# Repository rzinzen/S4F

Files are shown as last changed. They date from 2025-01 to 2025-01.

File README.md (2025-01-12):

# S4F
This project titled S4F ("Showers for Future") was designed and realized by Oliver R. Zinzen as a Science Fair project.
It descroibes an adapter compatible with 1/2-inch water pipes that houses a thermistor as a temperature sensor and which is to be combined with a commercially available Hall-Effect based 5V flow sensor. These sensors are meant to be connected to an Arduino Uno via a custom-solderd shield that also accomodates at 16x2 LCD display.
The following files are provided:
- Arduino Sketches
  - a main operating program called "S4F_vX.X" to read the sensors, address the LCD and monitor an input button.
  - a utility program called "S4F_CPLutility_v1.0" that helps determine the CPL (Counts per Liter) value 
- A wiring diagram for the electronics and how they are connected to the Arduino Uno
- A soldering plan for the custom shield
- STL 3D-model files so that the following items can be printed:
  - the Thermistor Housing with intrerenal 1/2-inch pipe threads
  - the enclosure that contains the electronics (Arduino Uno, electronics sield, main switch, battery, input button)

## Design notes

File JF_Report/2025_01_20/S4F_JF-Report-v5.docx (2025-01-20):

# S 4 F

# (Showers4Future)

Ein Jugend Forscht Projekt von

Oliver R. Zinzen (15 Jahre)

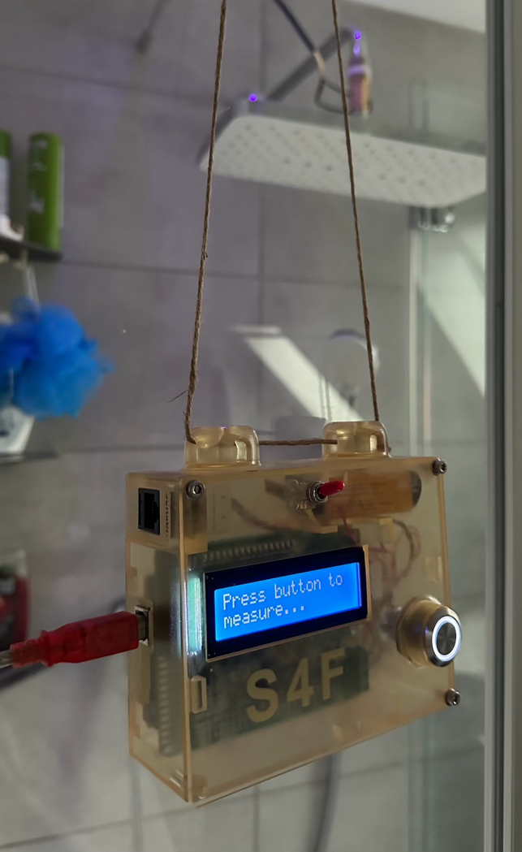
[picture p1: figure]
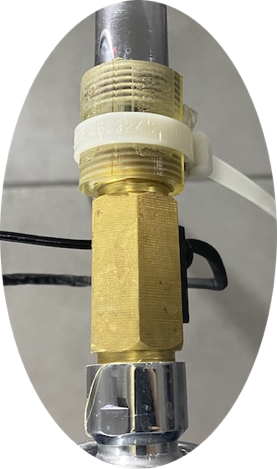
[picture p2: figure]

Fachgebiet: Physik

Wettbewerbsjahr: 2024/25

Bundesland: Brandenburg (West)

Barnim Gymnasium Bernau

Klasse 9M

Erarbeitungsort: hauptsächlich Zuhause

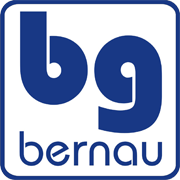
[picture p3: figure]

Betreuung:

- Fr. Hänsel (Mathematik & Physik)
- Fr. Gust (Mathematik & Physik)

# Projektüberblick

In meinem Projekt geht es darum, Wasser und Energie bewusster und sparsamer zu nutzen.

Ich habe einen Adapter für die Dusche entwickelt, mit dem die verbrauchte Wassermenge und -temperatur gemessen werden können. Ziel ist es, Verbrauchsinformationen leicht zugänglich zu machen, da ich überzeugt bin, dass solche Daten unser Verhalten positiv beeinflussen können, um Ressourcen und Kosten zu sparen.

Auf die Idee kam ich aus zwei Gründen: Zum einen bereiten uns die steigenden Energiepreise Sorgen, und zum anderen bedroht der Klimawandel unsere Zukunft. Ich glaube, dass intelligente technologische Ansätze uns dabei unterstützen können, umweltbewusster zu handeln.

Der von mir entwickelte Adapter wird beispielsweise an einer Duscharmatur installiert. Mithilfe eines Arduino-Mikrocontrollers werden die Sensoren für Temperatur und Wassergeschwindigkeit ausgelesen und die Daten dem Nutzer auf einem LCD-Display angezeigt. Ich habe den Adapter erfolgreich gebaut und bei uns zu Hause getestet, um erste Erfahrungen zu sammeln. Ich nenne ihn S4F („Showers for Future“).

Der Adapter hat gut funktioniert, aber es gibt noch viele Möglichkeiten zur Verbesserung. Zum Beispiel könnte er kleiner und kompakter gebaut werden, und es wäre sinnvoll, die erfassten Daten kabellos zu übertragen. Gerne würde ich S4F auch bei anderen Familien testen, um herauszufinden, ob die bereitgestellten Informationen nicht nur bei uns, sondern auch bei anderen Nutzern ein bewussteres und sparsameres Verhalten im Umgang mit Wasser und Energie fördern.

(Für Bild: siehe Titelseite)

# Inhaltsverzeichnis

# 1 Fachliche Kurzfassung

In meinem Projekt „S4F“ habe ich ein Gerät entwickelt, das Nutzer über ihren Wasser- und Energieverbrauch informiert.

Ein 3D-gedruckter Adapter, der zwischen Wasserarmatur (z.B. Duscharmatur) und Schlauch geschraubt wird, enthält Fluss- und Temperatursensoren und ist mit einem Arduino-Mikrocontroller verbunden. Die von mir entwickelte Software misst die Wassergeschwindigkeit und Temperatur und zeigt die ermittelten Werte auf einem LCD-Display an. Nach der Dusche berechnet das Gerät Verbrauchsdaten wie Duschzeit, Wassermenge, Durchschnittstemperatur, Energieverbrauch und Kosten und informiert den Nutzer darüber.

Das Ziel des Projekts ist es, den Nutzern Daten zur Verfügung zu stellen, die ein bewussteres und umweltfreundlicheres Verhalten ermöglichen.

# 2 Motivation und Fragestellung

Wasser und Energie sind essentielle Ressourcen, die wir täglich nutzen – sei es beim Duschen, Baden oder Händewaschen. Doch meist wissen wir nicht, wie viel Wasser und Energie wir dabei tatsächlich verbrauchen. In meiner Facharbeit möchte ich ein Gerät entwickeln, das hilft, unseren Wasser- und Energieverbrauch besser zu verstehen und diese wertvollen Ressourcen einzusparen. Hierzu plane ich, einen Adapter zu entwickeln, der an eine Wasserarmatur angeschlossen werden kann. Dieser Adapter misst Wasserfluss und Temperatur und informiert den Nutzer über den Verbrauch.

Die zentrale Fragestellung meiner Arbeit lautet: "Wie entwickle ich eine Elektronik, die Wasserfluss und Temperatur misst, die gesammelten Daten an den Nutzer übermittelt und wie integriere ich die Sensoren in einen Armatur-Adapter?" Mein Adapter soll "Showers4Future" (kurz: "S4F") heißen.

Dieses Thema fasziniert mich, weil es Technik und Umweltschutz miteinander verbindet. Ich bin überzeugt, dass wir genaue Informationen über unseren Verbrauch benötigen, um unser Verhalten gezielt und nachhaltig zu ändern. S4F soll uns dabei unterstützen, achtsamer mit Wasser und Energie umzugehen.

# 3 Hintergrund und theoretische Grundlagen

Die Idee für S4F kam mir im Winter 2022. Meine Familie war besorgt über die steigenden Energiekosten nach Russlands Invasion der Ukraine. Ich lebe mit meinen Eltern und drei Brüdern zusammen und mir wurde klar, dass wir viel Energie für Duschen verwenden. Aber niemand konnte mir genau sagen, wie viel Wasser und Energie wir tatsächlich beim Duschen verbrauchen. Also habe ich beschlossen, diesen Verbrauch zu messen.

Ich bin überzeugt, dass wir, wenn wir genaue Informationen über unseren Wasser- und Energieverbrauch hätten, gezielt darauf reagieren könnten. S4F soll nicht nur helfen wichtige Ressourcen zum Wohl der Umwelt zu schonen, sondern auch unsere Ausgaben zu reduzieren.

## 3.1 Temperaturmessung

Um die Temperatur zu messen, dachte ich sofort an einen Thermistor. Dieses elektronische Bauteil war mir zuvor in einem Arduino-Starter-Kit[^1] begegnet. Ein Thermistor ist ein elektrischer Widerstand mit der besonderen Eigenschaft, dass sein Widerstandswert von der Temperatur abhängt.

Bei meinen Recherchen im Internet stieß ich auf die sogenannte Steinhart-Hart-Gleichung. Mit dieser Gleichung lässt sich die Temperatur anhand des Widerstandswerts eines Thermistors berechnen[^2]. Die Herausforderung bestand jedoch darin, den Widerstand des Thermistors auszulesen, da dies nicht direkt mit einem Mikrocontroller wie z.B. einem Arduino möglich ist.

Dank meines Elektronik-Lernsets wusste ich, dass der Widerstand eines Thermistors indirekt gemessen werden kann, indem man ihn in einem Spannungsteiler verwendet und die Spannung über den Thermistor misst. Wenn die Spannung über den Thermistor und die Gesamtspannung des Spannungsteilers bekannt sind, lässt sich mithilfe des Ohm’schen Gesetzes der Widerstand des Thermistors berechnen. Den so ermittelten Widerstandswert kann ich schließlich in die Steinhart-Hart-Gleichung einsetzen, um die Temperatur zu bestimmen.

## 3.2 Wasserverbrauch

Ich habe mich im Internet nach Sensoren umgesehen, mit denen ich den Wasserverbrauch messen kann und bin dabei auf sogenannte Durchflusssensoren (Flow Sensors) gestoßen, die meist auf dem Hall-Effekt basieren.

Der Hall-Effekt beschreibt, dass Elektronen in einer geraden Linie durch eine leitfähige Platte wandern, wenn ein elektrischer Strom durch die Platte fließt. Befindet sich jedoch ein Magnet in der Nähe, werden die Elektronen zur Seite abgelenkt, wodurch eine Spannung über der Platte entsteht. Diese Spannung kann gemessen werden[^3].

Ein Durchflusssensor (Hall-Effekt-Sensor, HES) nutzt diesen Effekt: Er besitzt einen Propeller, der sich durch den Wasserfluss dreht. Die Propellerflügel sind dabei mit kleinen Magneten ausgestattet. Wenn sich der Propeller dreht, passieren die Magneten wiederholt den Hall-Effekt-Sensor und erzeugen Spannungsimpulse. Ich gehe davon aus, dass die Frequenz dieser Impulse proportional zur Wassergeschwindigkeit ist.

Diese Spannungsimpulse und ihre Frequenz sollte ich mit einem Mikrocontroller erfassen und zählen können, um so den Wasserverbrauch zu bestimmen.

## 3.3 Microcontroller

Um den Thermistor und den Hall-Effekt-Sensor (HES) auszulesen, plane ich, einen Mikrocontroller zu verwenden. Es gibt derzeit mehrere beliebte Plattformen, wie den Raspberry Pi und Arduino. Mikrocontroller sind Chips, die programmierbar sind und Signale verarbeiten und ausgeben können. Solche Mikrocontroller sind als sogenannte Entwicklungsboards (Dev.Kits) erhältlich, bei denen der Mikrocontroller-Chip über General Purpose Input/Output (GPIO)-Pins zugänglich ist. An diese Pins können Sensoren, Motoren oder andere Geräte angeschlossen werden, die durch Programmierung ausgelesen oder gesteuert werden können.

In einem vorherigen Projekt habe ich zusammen mit meinem Bruder einen Raspberry Pi verwendet, um in Python eine selbstoptimierende Wind- und Solaranlage (SoWiSo) zu entwickeln. Dabei fiel mir jedoch auf, dass der Raspberry Pi ein vollwertiger Unix-Computer ist und vergleichsweise viel Energie verbraucht. Da das S4F-Gerät batteriebetrieben sein soll, ist Energieeffizienz sehr wichtig.

Aus diesem Grund habe ich mich für die Arduino-Plattform entschieden. Arduino-Boards sind deutlich energiesparsamer als der Raspberry Pi und bieten dennoch ausreichend Leistung für mein Vorhaben. Das Arduino Uno R3 Dev. Kit kann entweder über eine 5 V-USB-Verbindung oder eine andere Gleichstromquelle (bis zu 12 V) betrieben werden. Es verfügt über 14 digitale und 6 analoge GPIO-Pins, die sich flexibel als Eingänge zum Einlesen von Signalen oder als Ausgänge zum Steuern von Geräten programmieren lassen.

Die Arduino-Plattform verwendet C++ als Programmiersprache. Der Code kann mit der kostenlosen Entwicklungsumgebung Arduino IDE (Integrated Development Environment)[^4] geschrieben und getestet werden. Zudem bietet die Arduino-Community eine ausgezeichnete Unterstützung: Es gibt zahlreiche Anleitungen, Foren und Codebeispiele, die den Einstieg erleichtern[^5]. Darüber hinaus ist es relativ einfach, ein Arduino-Board mit einem LCD-Display zu verbinden, um dem Nutzer Anweisungen anzuzeigen oder Daten zu präsentieren.

# 4 Vorgehensweise, Materialien und Methoden

## 4.1 Elektronik und Prototyp

Den ersten Prototyp zur Auslesung der Sensoren mit einem Arduino habe ich mithilfe einer Steckplatine entwickelt. Diese ermöglicht es, elektronische Komponenten durch einfaches Einstecken von Jumper-Kabeln zu verbinden. Eine Liste der verwendeten Komponenten befindet sich im Anhang (9.1). Die wichtigsten Komponenten sind:

- Arduino Uno R3 Dev. Kit: Ein Arduino-Entwicklerboard als Steuereinheit.
- Durchflusssensor[^6]: Kann mithilfe des Hall-Effekts Durchflussmengen zwischen 1 und 30 L/min messen.
- Thermistor: Ein NTC-Temperatursensor (TRU Components, Modell MJSTS-103-3950-1-600-3D[^7]) mit einem 10 kΩ Referenzwiderstand bei 25 °C.
- Steckplatine und Elektronikkomponenten: Die Steckplatine sowie verschiedene Bauteile (Widerstände, Taster, Potentiometer, Jumper-Kabel, LCD-Display) stammen aus mehreren Elektronik-Lernsets1,[^8],[^9].

Mit dieser Hardware konnte ich die grundlegenden Funktionen des Prototyps testen und die Sensoren erfolgreich mit dem Arduino integrieren.

## 4.2 Programmieren

Für die Programmierung habe ich die Software Arduino IDE4 verwendet. Mit dieser Entwicklungsumgebung kann man C++ Code schreiben, auf Syntaxfehler prüfen und anschließend auf ein Arduino-Board übertragen. Ein besonders nützliches Feature der Arduino IDE ist der Serial Monitor. Dieser ermöglicht es, dass der Arduino während des Programmablaufs Nachrichten sendet. So können potenzielle Probleme im Code einfach diagnostiziert und behoben werden. Die Grundlagen der Programmierung eines Arduino habe ich mithilfe eines Arduino-Übungsbuchs8 gelernt. Bei Fragen oder Herausforderungen konnte ich meist hilfreiche Antworten im Arduino-Wiki5 finden.

## 4.3 Löten

Nachdem ich einen funktionierenden Prototyp auf einer Steckplatine gebaut hatte, plante ich, ein „Shield“ zu erstellen. Ein Shield ist eine Platine, die auf den Arduino aufgesteckt werden kann und auf der alle Schaltkreise fest verlötet sind.

Zunächst habe ich mit der CAD-Software Autodesk Eagle[^10] die Schaltkreise aufgezeichnet und dokumentiert, wie diese mit dem Arduino und dem LCD-Display verdrahtet waren. Anschließend entwickelte ich einen detaillierten Lötplan.

Die Umsetzung erfolgte auf einer Lochrasterplatine (90 mm x 70 mm, Rastermaß 2,54 mm). Alle benötigten Komponenten wurden gemäß des Lötplans auf die Platine aufgebracht, mit Silberdraht verbunden und verlötet, um eine robuste und dauerhafte Verbindung zu gewährleisten.

## 4.4 3D-Design & 3D-Druck

Für das S4F-Gerät habe ich zwei Bauteile selbst gedruckt: die Thermistor-Halterung, die mit der Armatur und dem Flusssensor verschraubt wird, sowie das Gehäuse für die Elektronik. Beide Teile habe ich mit der Software Autodesk Fusion 360[^11] entworfen.

Die 3D-Modelle habe ich anschließend als STL-Dateien exportiert und mit einem 3D-Drucker (Keyence Agilsta 3200 W[^12]) gedruckt. Der Agilsta ist ein professioneller 3D-Drucker, der anstelle des herkömmlichen PLA-Filaments einen foto-aktivierbaren Druck-Harz verwendet. Dadurch kann der Agilsta eine höhere Auflösung sowie bessere Materialfestigkeit und Hitzebeständigkeit erreichen.

## 4.5 Implementierung zu Hause

Das erste S4F Gerät habe ich in unserer Dusche zu Hause installiert, und wir haben es circa eine Woche lang benutzt. Von unseren ersten Erfahrungen werde ich berichten.

# 5 Ergebnisse

Die Entwicklung des S4F-Geräts hat längere Zeit in Anspruch genommen. Besonders beim ersten Prototyp auf der Steckplatine musste ich regelmäßig Komponenten ändern und umstecken, was parallel zur Softwareentwicklung lief. Zum Beispiel, als ich auf die Idee kam, ein LCD-Display zu verwenden, musste ich die Verkabelung komplett überarbeiten, um die benötigten GPIO-Pins zu belegen und die Betriebssoftware darauf abzustimmen. Ebenso, als ich mehr über die Thermistor-Temperatur-Berechnung recherchierte, musste ich einen neuen Spannungsteiler implementieren. In den folgenden Ergebnissen werde ich deshalb hauptsächlich die Endergebnisse darstellen, aber keine detaillierte Beschreibung der Umwege und Anpassungen während der Entwicklung geben.

## 5.1 Der Prototyp

Den ersten Prototypen habe ich auf einer Steckplatine verkabelt, wobei der Arduino über USB mit 5 V versorgt wurde. Das Steckbrett ist in Abbildung 1B dargestellt, und der schematische Schaltplan ist in Abbildung 1 A zu sehen. Die wichtigsten Komponenten des Prototyps sind:

- Arduino Uno R3 Mikrocontroller mit 14 digitalen GPIOs und 6 analogen GPIOs (die auch als digitale Pins genutzt werden können). Zusätzlich verfügt der Arduino über mehrere Power-Pins, von denen ich den „5 V“-Pin als positiven Pol (5 V+) und den „Gnd“-Pin als negativen Pol (Gnd) für meine Schaltung verwendet habe.
  - 16x2 LCD-Display Modul: Das Display kann 16 Zeichen in 2 Reihen darstellen. Wie im Arduino Wiki beschrieben[^13], ist das LCD-Display mit 5 V+ und Gnd verbunden. Der V0-Pin des Displays ist mit einem 10 kΩ Potentiometer verbunden, um den Displaykontrast durch Regulierung des elektrischen Potentials am V0-Pin einzustellen. Um dem Arduino das Senden von Text an das Display zu ermöglichen, ist der Arduino mit den Pins En, RS sowie D4, D5, D6 und D7 des Displays verbunden. Dadurch werden insgesamt 6 digitale GPIO-Pins des Arduinos benötigt.
  - Taster: Ein Taster ermöglicht es dem Arduino, auf Nutzereingaben zu reagieren. Wenn der Taster betätigt wird, schließt er einen Stromkreis zwischen 5 V+ und Gnd über einen 10 kΩ Widerstand, wodurch der digitale Pin auf 5 V gesetzt wird. Ein 7. Digitaler Pin wird so programmiert, dass er den Unterschied zwischen 0V (LOW, offen) und 5 V (HIGH, geschlossen) erkennt, womit der Arduino auf die Knopfbetätigung reagieren kann.
  - Hall-Effekt-Sensor: Der Hall-Effekt-Sensor hat drei Kabel. Zwei (rot und schwarz) dienen der Stromversorgung und sind an 5 V+ und Gnd angeschlossen. Über das dritte Kabel (grün) wird der Hall-Impuls an einen 8. digitalen GPIO-Pin übertragen, die vom Arduino dann gezählt werden können.
  - Thermistor: Um den Thermistor auszulesen, verwende ich einen Spannungsteiler, bei dem ein konstant bleibender Widerstand (R5) und der temperaturabhängige Thermistor in Reihe zwischen 5 V+ und Gnd geschaltet sind. Da der Thermistor einen Referenzwert von 10 kΩ bei 25°C hat, habe ich einen 10 kΩ Widerstand als konstante Komponente verwendet. So wird die Spannung bei 25 °C halbiert und Widerstandsunterschiede im Thermistor sollten gut erfassbar sein. Die Spannung über den Thermistor wird an einen 9. GPIO-Pin des Arduinos übertragen. Dies muss ein analoger Pin sein, damit der Arduino die Größe der Spannung wie in 5.2 beschrieben auslesen kann.

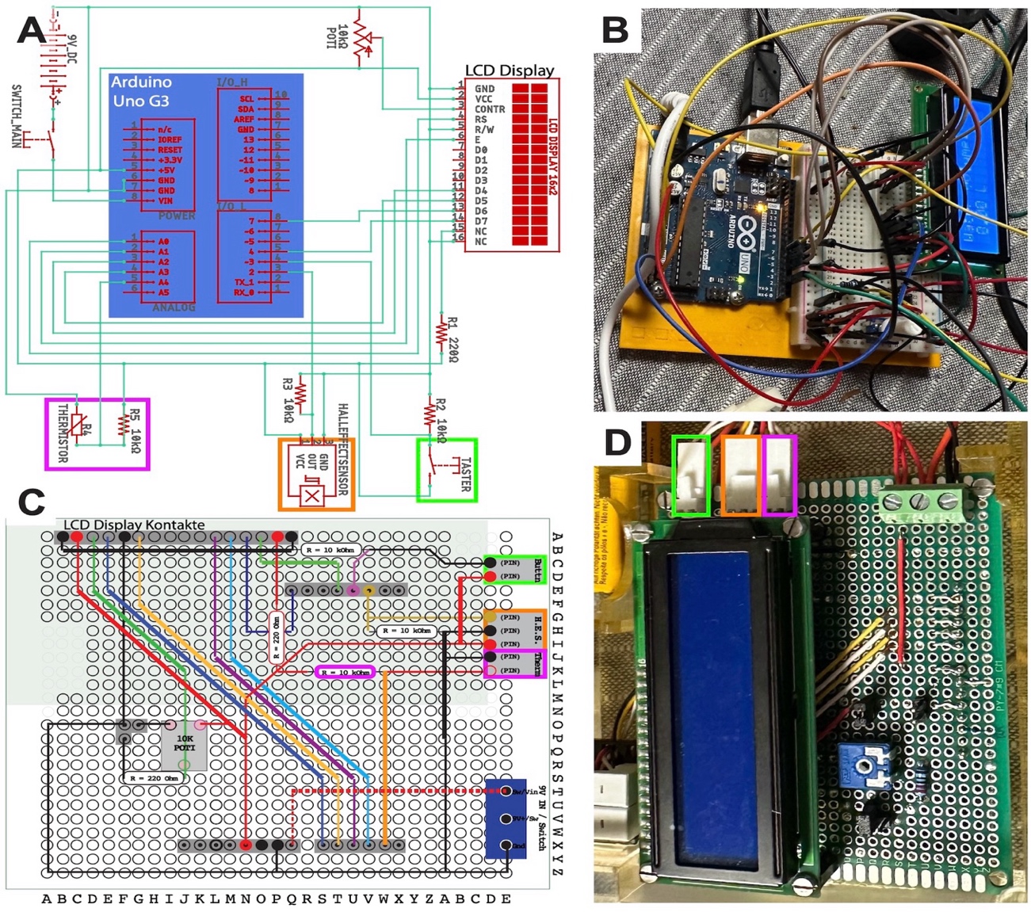
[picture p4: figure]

Abbildung 1: Prototyp-Schaltplan uns Shield-Entwicklung

Der Schaltplan (A) basiert auf dem Steckbrett Prototyp (B). Auf (A) basierend wurde ein Lötplan (C) entwickelt was mir erlaubte ein Arduino-Shield mit fest verlöteten Elektronik-komponenten zu bauen (D). Einige Komponenten sind umrahmt (Thermistor in rosa, HES in orange, Input Taster in hellgrün). Detaillierte Pläne stehen zum Download auf GitHub bereit[^14].
(Alle Abbildungen in dieser Arbeit wurden eigenständig erstellt.)

Nachdem der funktionierende Schaltplan stand (Abbildung 1A, B), um den Taster, den Thermistor und den Hall-Effekt-Sensor auszulesen, habe ich mir einen Lötplan erstellt (Abbildung 1C). Anschließend habe ich die Schaltung auf einer Lochrasterplatine umgesetzt (Abbildung 1D). Da ich eine Platine mit einem Lochrastermaß von 2,54 mm verwendete, konnte ich die Lötstiftleisten so anordnen, dass die Platine direkt auf den Arduino aufgesteckt werden konnte, um eine stabile Verbindung zu gewährleisten. Zusätzlich habe ich eine Kontaktleiste eingelötet, sodass das LCD-Display mit seinen 16 Stiften direkt auf die Platine aufgesetzt werden kann. Dies ermöglichte es, das Display und den Arduino bei Bedarf wieder zu trennen, falls ich Änderungen an der Platine vornehmen muss.

## 5.2 Implementierung des Thermistors zur Temperaturmessung

### 5.2.1 Berechnung des Thermistorwiderstands

Da der Thermistrorwiderstand R_(Ther) mit einem Arduino nicht direkt ausgelesen werden kann, werde ich ihn mit Hilfe des Ohm’schen Gesetzes[^15] anhand der gemessenen Spannung berechnen ( R_(Ther) = (U_(Ther))/I ). Die Spannung über den Thermistor U_(Ther) kann über die analogen GPIO-Pins eingelesen werden, da diese mit einem 10-Bit-ADC (Analog-to-Digital Converter) ausgestattet sind. Der ADC wandelt die Spannung am Pin relativ zur internen Referenzspannung ( U_(In) = 5 V ) in einen Wert zwischen 0 – 1023 (10-Bit-Auflösung) um.

Ich benutze einen Spannungsteiler, der aus zwei Widerständen in Reihe besteht: R1 (ein konstanter Widerstand von 10 kΩ) und RTher (der Widerstand des Thermistors).

Der Gesamtwiderstand des Spannungsteilers ist: R_(Ges) =R_1 +R_(Ther)

Nach dem Ohm‘schen Gesetz15 gilt: U_(In) =R_(Ges) ∙I_(Ges) =(R_1 +R_(Ther) )∙I

Daraus folgt: I_(Ges) = (U_(In))/((R_1 +R_(Ther) ))

Die 5 V Eingangsspannung teilt sich über Widerstände in Reihe auf: U_(In) =U_1 +U_(Ther)

Die Spannung über den Thermistor ist nach dem Ohm‘schen Gesetz definiert als:

U_(Ther) =R_(Ther) ∙I_(Ther) ⇔ I_(Ther) = (U_(Ther))/(R_(Ther))

Da die Stromstärke überall im Stromkreis gleich ist gilt I_(Ges) =I_(Ther) und der Widerstand des Thermistors RTher kann berechnet werden:

(U_(Ther))/(R_(Ther)) =(U_(In))/((R_1 +R_(Ther) ))

Nach Umstellung: R_(Ther) =(R_1)/(((U_(In))/(U_(Ther)) - 1))

Mit R_1 =10 kΩ , U_(In) =5 V , und dem Wert für UTher, den der Arduino über den ADC ausliest kann der Thermistorwiderstand R_(Ther) berechnet werden.

### 5.2.2 Temperaturberechnung

Mit Hilfe der Steinhart-Hart-Gleichung lässt sich die Temperatur T aus dem Widerstand R_(Ther) berechnen:

T_(Kelvin) =1/((A + B∙ ln(R_(Ther) )+ C∙ (ln(R_(Ther) ))^3 ))

Die Werte A, B, und C Thermistor-spezifische Konstanten, die ich mit einem Online-Thermistor Rechner[^16] und den Widerstandswerten aus dem Thermistor Datenblatt7 ermittelt habe:

A=1,105646556∙10^(-3) B=2,369707092∙10^(-4) C=8,420273017∙10^(-8)

Um die Temperatur in °C umzurechnen, ziehe ich anschließend noch 273,15 ab: T_(Celsius) = T_(Kelvin) – 273,15

## 5.3 Ermittlung des CPL-Werts

Um eine zuverlässige Konstante zur Umrechnung der Hall-Effekt-Impulse in Liter zu ermitteln, habe ich die CPL-Konstante (Counts per Liter) bestimmt. Diese Konstante ermöglicht es dem Arduino, das verbrauchte Wasservolumen durch einfache Division der gezählten Impulse durch den CPL-Wert zu berechnen.

### 5.3.1 Versuchsaufbau

Ich habe ein Utility-Programm (Arduino Sketch verfügbar auf GitHub14) geschrieben, dass die Hall-Effekt-Impulse zählen. Der Start und Stopp der Zählung erfolgten über einen Knopf. Der Versuch wurde folgendermaßen durchgeführt:

1. Durchflusssensor wurde direkt an der Duscharmatur installiert.
2. Ein Eimer wurde mit Markierungen bei 5 L, 8 L und 10 L versehen.
3. Während das Wasser in den Eimer lief, zählte das Programm die Impulse. Nach Erreichen einer bestimmten Markierung wurde die Zählung gestoppt.

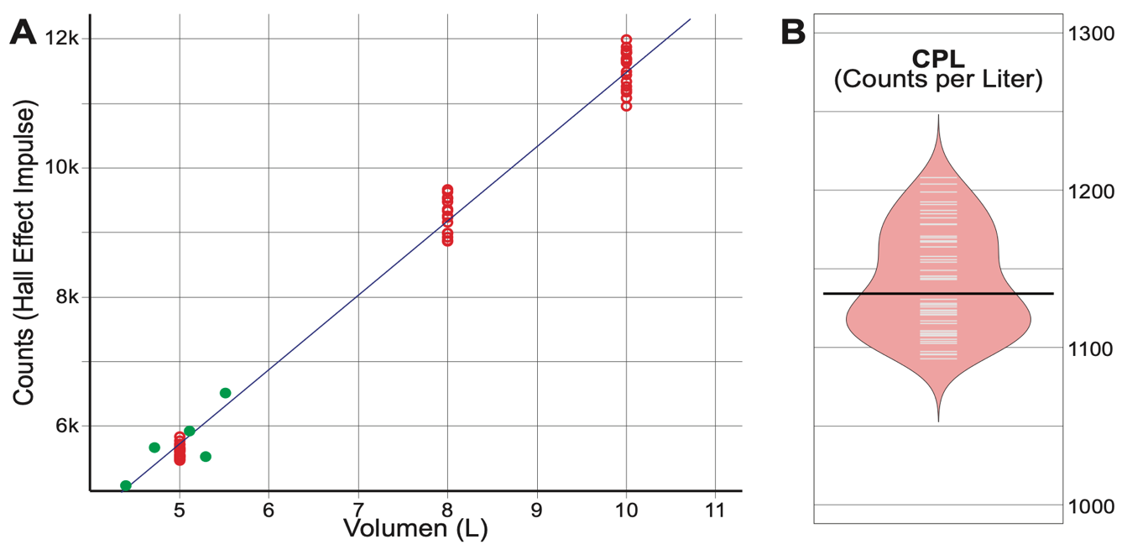
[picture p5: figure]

Abbildung 2: CPL-Ermittlung.

(A) Die roten Punkte sind die gemessenen Impulszahlen des HES. Die Trendlinie durch den Null-Punkt hat einen R²-Wert von 0,9991. Die grünen Punkte sind Punktprüfungen zur Validierung des CPL-Werts.
(B) Die 51 Messwerte sind in einem Bean-Plot als Counts pro Liter dargestellt und zeigen eine enge Verteilung, Median = 1134,2 CPL.

4. Variationen: Der Test wurde mit verschiedenen Wassermengen und Wassergeschwindigkeiten (Hahnöffnung) durchgeführt.

Ich habe diesen Vorgang 51-mal wiederholt und dabei die gezählten Impulse sowie die jeweilige Wassermenge notiert. Alle Messwerte sind im Anhang 9.1 aufgeführt.

### 5.3.2 Datenanalyse

Ein Scatterplot der Count-Werte für 5 L, 8 L und 10 L (Abbildung 2A) zeigt eine nahezu lineare Beziehung zwischen den gezählten Impulsen und der Wassermenge. Eine Trendlinie, berechnet in Excel, liefert einen R²-Wert von 0,9991. Dies deutet darauf hin, dass die CPL-Konstante eine präzise Vorhersage der verbrauchten Wassermenge ermöglicht. Die Trendlinie wird durch die lineare Gleichung y=1148,3∙x beschrieben, wobei die Steigung der CPL-Wert ist:

CPL_(lin) =1148,3

Eine Bean-Plot-Darstellung (Abbildung 2B) der auf 1 L-normalisierten Counts (CPL) verdeutlicht die enge Verteilung der Messwerte im Bereich von ca. 1100 bis 1200 CPL, mit einem Median=1134,2 CPL . Dies ist ein CPL-Wert, der auf einer statistischen Verteilung der Datenpunkte beruht.

CPL_(stat) =1134,2

Auch den Durchschnitt der 51 CPL-Werte könnte man nehmen um den Arduino Impulszählungen in Wasservolumen umrechnen zu lassen:

CPL_(Schnitt) =1141,25

### 5.3.3 Validierung des CPL-Werts

Zur Validierung des CPL-Werts habe ich Test durchgeführt. Ich habe den Eimer mehrmals für eine unbestimmte Zeit (10 – 30 Sekunden) gefüllt während der Arduino die Impulse zählte. Die exakte Wassermenge habe ich anschließend mit einer Küchenwaage bestimmt (1 g Wasser = 1 mL). Die Ergebnisse sind als grüne Punkte im Scatterplot (Abbildung 2A) eingezeichnet und Tabelle 1 aufgeführt

Das gemessene Volumen habe ich mit den für alle 3 CPL-Werte ermittelt, wobei ich die Genauigkeit der 3 CPL-Werte vergleichen wollte. Die Ergebnisse sind in Tabelle 1 aufgeführt.

Tabelle 1: Validierung des bestimmten CPL-Werts

| | | CPLLin = 1148,3 | | CPLStat = 1134,2 | | CPLSchnitt = 1141,25
Nr. | Counts | f | Erwartet (L) | Fehler (%) | Erwartet (L) | Fehler (%) | Erwartet (L) | Fehler (%)
1 | 5098 | 4,385 | 4,440 | 1,245 | 4,495 | 2,504 | 4,467 | 1,871
2 | 5935 | 5,107 | 5,169 | 1,204 | 5,233 | 2,463 | 5,200 | 1,830
3 | 5549 | 5,289 | 4,832 | -8,634 | 4,892 | -7,498 | 4,862 | -8,069
4 | 5680 | 4,708 | 4,946 | 5,065 | 5,008 | 6,371 | 4,977 | 5,714
5 | 6522 | 5,509 | 5,680 | 3,099 | 5,750 | 4,380 | 5,715 | 3,735
Fehler-Durchschnitt: | | | | 1,40 | | 1,64 | | 1,02

Obwohl alle 3 CPL-Werte gute vorhersagen trafen, war der Durchschnittswert etwas besser, denn die berechneten Werte wichen im Schnitt um weniger als ±2 % von der gemessenen Wassermenge ab. Dies zeigt die die Genauigkeit der CPL-Konstante und ich werde den Wert CPL = 1141,25 in meinem Arduino Sketch verwenden.

## 5.4 Die Software

Ein Arduino-Programm wird als “Sketch” bezeichnet. Der S4F-Sketch für Version 2.1[^17] umfasst 354 Zeilen und ist auf GitHub verfügbar14. Der Code ist ausführlich kommentiert, um die einzelnen Schritte und die Funktionsweise des Programms zu verdeutlichen. Die Programmstruktur ist in Abbildung 3 dargestellt. Das Programm ist in verschiedene sogenannte Funktionen unterteilt, wobei jede Funktion einen bestimmten logischen Ablauf umfasst. Diese Funktionen können miteinander kombiniert werden, um die gewünschte Programmlogik zu realisieren.

Wenn das S4F-Gerät gestartet wird, bootet der Arduino direkt in das Betriebsprogramm. Zunächst wird eine library eingebunden, die die Kommunikation mit dem LCD-Display ermöglicht. Anschließend werden innerhalb von Millisekunden verschiedene Variablen und Konstanten definiert, darunter die GPIO-Pins für den Taster, das LCD-Display und den Hall-Effekt-Sensor. Auch thermistorspezifischen Konstanten (A, B, C) sowie CPL werden an dieser Stelle definiert. Ein Arduino-Sketch besteht immer aus zwei Hauptfunktionen: setup() und loop().

In der setup()-Funktion wird festgelegt, wie sich die einzelnen Pins verhalten sollen. Beispielsweise wird der Pin für den Taster („ButtonPin“) sowie der für den Hall-Effekt-Sensor („HallPin“) als „INPUT“ definiert, sodass der Arduino diese Pins kontinuierlich überwachen kann. Der HallPin wird zusätzlich mit einem attachInterrupt()[^18] versehen, wodurch der Arduino unabhängig vom restlichen Programm Spannungsänderungen an diesem Pin registriert. Jede Spannungsänderung – also jeder Impuls des Hall-Effekt-Sensors – ruft die Funktion CountHallPulses() auf, die eine Variable namens HallCount um 1 erhöht und damit die Impulse zählt.

Zusätzlich werden in der setup()-Funktion alle relevanten Variablen auf ihren Anfangswert gesetzt. Danach wird eine Willkommensnachricht auf dem LCD-Display angezeigt, die den Benutzer auffordert, den Taster zu drücken, um die Messungen zu starten. Das Programm wartet anschließend in einer Schleife (while-Loop), bis der Taster gedrückt wird und sich damit die Spannung am ButtonPin sich ändert.

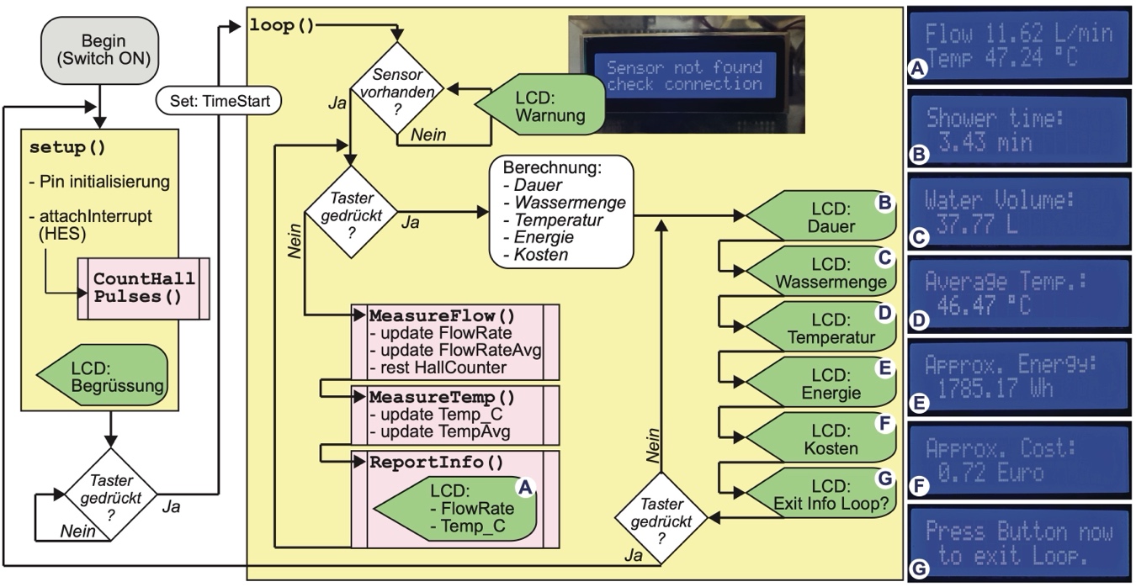
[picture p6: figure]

Abbildung 3: Diagramm der Software-Logik (Version 2.1) mit LCD-Display Beispielen

Nach Betätigung des Tasters wird die Startzeit (TimeStart) festgelegt, und das Programm wechselt zur Hauptfunktion eines jeden Arduino-Sketches: der loop()-Funktion. Diese wird kontinuierlich wiederholt und bildet das Herzstück des Programms.

Zu Beginn der loop()-Funktion überprüft das Programm, ob die Sensoren angeschlossen sind. Falls der Thermistor-Schaltkreis offen ist (keine Sensoren angeschlossen), ist der Widerstand unendlich groß, was zu einem Temperaturwert von -273,15 °C (0 K) führt. In diesem Fall zeigt das Display eine Fehlermeldung an und fordert den Benutzer auf, die Sensorverbindungen zu prüfen.

Wenn die Sensoren korrekt arbeiten, beginnt das Programm mit den Messungen. Alle sechs Sekunden wird die Funktion MeasureFlow() aufgerufen, um die aktuelle Durchflussrate zu berechnen. Die Wassertemperatur wird alle zwei Sekunden mit der Funktion MeasureTemp() gemessen. Beide Werte werden im Zwei-Sekunden-Takt mit ReportInfo() auf dem Display aktualisiert.

Die Funktion MeasureFlow() berechnet die aktuelle Durchflussrate (FlowRate) in L/Minute, indem sie die Anzahl der gezählten Hall-Impulse (HallCount) durch die Konstante CPL teilt und das Ergebnis mit 10 multipliziert (da die Funktion alle 6 Sekunden aufgerufen wird). Zusätzlich wird der Durchschnitt der Durchflussrate berechnet. Abschließend setzt die Funktion HallCount auf 0 zurück, um die nächste Messung vorzubereiten. Die Funktion MeasureTemp() berechnet die aktuelle Wassertemperatur (Temp_C), wie in Abschnitt 5.2 beschrieben. Auch hier wird der Durchschnittswert der Temperatur berechnet.

Wenn der Taster nach der Dusche erneut gedrückt wird, beendet das Programm den Messzyklus und definiert die Stopp-Zeit. Anschließend werden die ermittelten Werte nacheinander auf dem Display angezeigt:

- Duschzeit: Duration(min)= TimeStart-TimeStop
- Wasserverbrauch: Volume(L) = FlowRateAvg(L/min) ∙ Duration(min)
- Schnitttemperatur: TempAvg(°C)
- Energieverbrauch: Energy(Wh) = (Volume(L)∙c_Water(kWh)∙(TempAvg(°C)-TempBase(°C)))/(1000 (L∙°C) ∙ 0,7)
- Kosten: Cost(Euro) = (Energy∙EnergyPrice)+(Volume∙WaterPrice)

Die letzten beiden Werte – Energieverbrauch und Kosten – dienen lediglich der Orientierung, da sie von mehreren Faktoren beeinflusst werden und daher weniger präzise sind. Der Energieverbrauch hängt insbesondere von der spezifischen Wärmekapazität des Wassers (c_Water), der Temperatur des kalten Leitungswassers (TempBase) sowie von der Effizienz des Warmwasserbereitungs- und Speichersystems ab. Da die Effizienz solcher Systeme typischerweise zwischen 60 % und 80 % liegt, habe ich einen realistischen Wert von 70 % verwendet und den Energiewert entsprechend nach oben angepasst, indem ich durch 0,7 teile.

Die Berechnung der Kosten ist ebenfalls ungenau, da sie von den lokalen Energie- und Wasserpreisen abhängt. Der Energiepreis wird variieren, je nachdem, ob das Wasser z.B. mit Strom, Gas oder Öl erhitzt wird. Für die Berechnung habe ich Werte basierend auf realistischen Preisen im Landkreis Barnim verwendet[^19]: 0,28 Euro/kWh Energie und 5,86 Euro/m³ Wasser (inkl. Abwasser).

## 5.5 3D-Design und Druck

Um den Temperatursensor zu integrieren, habe ich ein Gehäuse für den Thermistor entworfen und mit einem 3D-Drucker hergestellt (Abbildung 4A). Da Wasserarmaturen in der Regel ein ½-Zoll-Gewinde besitzen und der Durchflusssensor auf beiden Seiten mit einem ½-Zoll-Außengewinde ausgestattet ist, entschied ich mich, das Thermistorgehäuse mit ½-Zoll-Innengewinden zu entwerfen. Wenn der Fluss- und der Temperatursensor miteinander verschraubt werden, ergibt sich an einem Ende ein Innen- und am anderen Ende ein Außengewinde. Dadurch kann der Adapter problemlos zwischen Armatur und Schlauch montiert werden. Der Thermistor wird mittig in das Gehäuse eingesetzt und mit Silikon wasserdicht versiegelt. Im Inneren des Gehäuses befinden sich zwei Ablagen, die Platz für Gummidichtungen bieten (Abbildung 4B).

Das Gehäuse für die Elektronik wurde exakt auf die Maße des Arduinos, der Platine und des LCD-Displays abgestimmt (Abbildung 4C, D). Der Arduino wird eingelegt, so dass der USB-B-Anschluss zugänglich bleibt. Anschließend wird das verlötete Elektronik-Shield auf den Arduino gesteckt und mit dem Gehäuse verschraubt. Danach wird das LCD-Display auf das Shield aufgesteckt und mit Schrauben befestigt. Eine 9 V-Batterie wird in die vorgesehene Aussparung eingelegt und mit dem Shield verbunden. Die Sensoren werden über einen RJ45-Keystone-Stecker[^20] angeschlossen, der in das Gehäuse integriert wird und mit den entsprechenden Ports des Shields verbunden ist. Im Gehäusedeckel befinden sich ein Schalter, mit dem die Batterie vom Stromkreis getrennt werden kann, sowie ein Taster, der mit dem Knopf-Port des Shields verbunden ist. Schließlich wird der Deckel auf das Gehäuse geschraubt, sodass das LCD-Display durch eine Aussparung sichtbar ist. Das Gerät ist damit einsatzbereit. Am Gehäuse befindet sich eine Halterung, die es ermöglicht, das S4F-System außen an der Dusche zu befestigen. So können die Daten während des Duschens abgelesen werden (siehe Bild auf Titelseite).

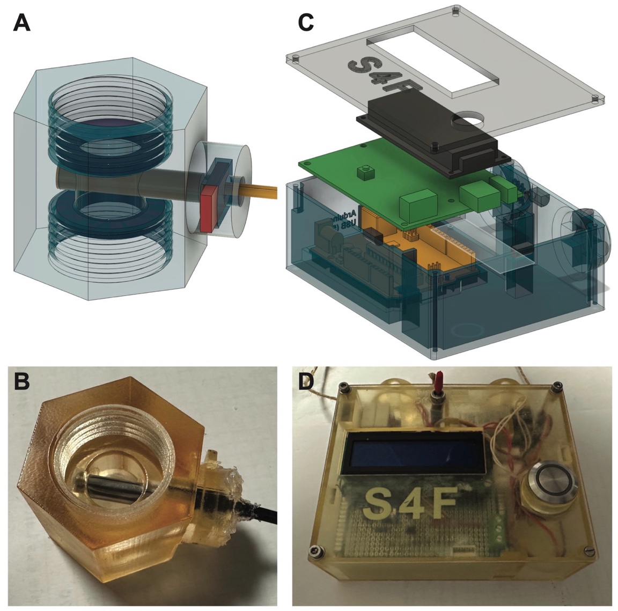
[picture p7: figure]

Abbildung 4: 3D-Modelle und Druckergebnisse

Zu sehen sind die 3D-Modelle für (A) die Thermistorhalterung und (C) das Gehäuse für die Elektronik. (B) und (D) zeigen die gedruckten und zusammengebauten Komponenten.

# 6 Ergebnisdiskussion, Fazit und Ausblick

In meinem Projekt „S4F“ habe ich einen Adapter entwickelt, der auf gängige Wasserarmaturen mit ½-Zoll-Gewinde passt. Dieser Adapter enthält Sensoren, die Wassermenge und -temperatur messen. Die Sensoren sind über eine eigens entwickelte Elektronik mit einem Arduino-Mikrocontroller verbunden. Arduino, Elektronikplatine und ein LCD-Display sind in einem 3D-gedruckten Gehäuse untergebracht.

Das S4F Arduino Betriebssystem misst kontinuierlich Wassermenge und -temperatur und zeigt die Werte auf dem LCD-Display an. Durch erneuten Knopfdruck beendet der Nutzer das Programm. Anschließend berechnet und zeigt der Arduino 5 Werte: (i) Duschzeit, (ii) Wasserverbrauch, (iii) Durchschnittstemperatur, (iv) Energieverbrauch und (v) ungefähre Kosten.

## 6.1 Erste Eindrücke

Nach der Installation des ersten S4F-Geräts in unserer Dusche haben wir interessante Einblicke in unser Duschverhalten gewonnen. Die gesammelten Daten führten zu spannenden Gesprächen in der Familie. Besonders aufschlussreich war es zu sehen, wer am längsten und wer am heißesten duscht. Unsere Durchschnittswerte sind:

- Duschdauer: 6,92 Minuten
- Wasserverbrauch: 60,02 Liter
- Durchschnittstemperatur: 42,96 °C
- Energieverbrauch: 2510,63 Wh
- Ungefähre Kosten: € 1,07

Die teuerste Dusche, die wir bisher gemessen haben, dauerte 13,61 Minuten bei 46,38 °C, verbrauchte 98,90 L und kostete etwa € 1,88. Diese Zahlen waren für uns ein Weckruf. Bei sechs Familienmitgliedern könnten sich unsere jährlichen Duschkosten auf etwa €2343,30 belaufen (€ 1,07 · 365 Tage · 6 Personen).

Die Informationen, die wir jetzt mit Hilfe der S4F haben, machen uns unseren Ressourcenverbrauch erst richtig bewusst und motivieren uns, nachhaltiger zu handeln. Wir haben uns vorgenommen, unsere Duschgewohnheiten zu ändern, um Wasser, Energie und Kosten zu sparen. Das Material für S4F hat uns ca. € 90 gekostet (siehe 9.1), eine Summe, die wir in wenigen Monaten einsparen könnten.

## 6.2 Zukunft

Es gibt viele Möglichkeiten, S4F weiterzuentwickeln und noch nützlicher zu machen. Meine Mutter wünscht sich z.B., dass das Display die Duschzeit anzeigt, so dass man den Verbrauch besser steuern kann. Sollte ich das Projekt für Jugend forscht 2025/26 weiterverfolgen, würde ich zuerst daran arbeiten, die erfassten Daten nach der Dusche per E-Mail an die Nutzer zu senden. Dafür wäre jedoch ein anderer Mikrocontroller nötig, da der von mir verwendete Arduino Uno G3 nicht kabellos kommunizieren kann. Eine mögliche Alternative wäre der Arduino Uno G4 mit WLAN oder ein ESP32-Mikrocontroller, der sowohl WLAN als auch Bluetooth unterstützt.

Zwar weiß ich noch nicht wie kompliziert es ist mit einem Microcontroller E-Mails zu versenden, aber wenn mir das Gelingt könnte ich das System auch noch verbessern indem vor jeder Dusche ein Benutzer ausgewählt wird. So könnten die Daten personenspezifisch gespeichert und versendet werden. Über einen längeren Zeitraum ließen sich dann individuelle Zeitprofile erstellen.

Die Nutzung von WLAN würde jedoch den Energieverbrauch erhöhen. Derzeit verwende ich eine 9 V-Batterie, die über einen Spannungsregler auf 5 V heruntergeregelt wird. Dabei geht jedoch viel Energie als Wärme verloren. Eine effizientere Lösung wäre ein wiederaufladbarer Akku, der über einen Boost-Converter den Arduino mit stabilen 5 V versorgt. Dies wäre nicht nur energieeffizienter, sondern auch umweltfreundlicher.

Ich kann mir vorstellen, dass ein Unternehmen den S4F Prototyp professionell entwickelt und herstellt. Die Elektronik könnte so miniaturisiert werden, dass der Adapter nur ein wenig größer als der Durchflusssensor selbst wäre, denn der Mikrokontroller-Chip ist nur so groß wie ein Fingernagel. Der Thermistor kann auch wesentlich kleiner sein und direkt beim Propeller angebracht sein. Statt LCD Display könnte das Modul direkt mit einer App (z.B. über Bluetooth) Informationen geben und Daten loggen. Eine Knopfbatterie würde wahrscheinlich genug Strom liefern, aber vielleicht wäre es sogar möglich den Propeller als Turbine zu nutzen um Spannung zu generieren und einen kleinen Akku zu laden[^21].

## 6.3 Ein sozialwissenschaftliches Experiment

Eine weitere interessante Anwendung für S4F wäre ein kleines sozialwissenschaftliches Experiment. Ich könnte ein verbessertes Gerät für einige Wochen an verschiedene Familien meiner Klassenkameraden verleihen. Mit deren Einwilligung könnten die gesammelten Daten über WLAN auch an mich gesendet werden. Den Familien würde ich die ausgewerteten Daten selbstverständlich zur Verfügung stellen. Ich würde die anonymisierten Daten für mein nächstes Jugend forscht-Projekt verwenden, um zu untersuchen, ob und wie sich das Duschverhalten durch den Einsatz von S4F verändert. Das Projekt könnte Aufschluss darüber geben, wie technische Lösungen Menschen zu einem nachhaltigeren Verhalten motivieren können.

# 7 Quellen- und Literaturverzeichnis

# 8 Unterstützungsleistungen

Ich möchte mich besonders bei Fr. Hänsel für ihre Betreuung meiner Jugend Forscht Arbeit bedanken.

Ich möchte mich auch bei Frau Gust bedanken, die meine Facharbeit betreut hat und die mir erlaubt hat die Facharbeit mit dem Jugend Forscht Projekt zu kombinieren.

Ich will mich bei meinem Vater für seine Hilfe beim Löten und Programmieren bedanken.

Schließlich möchte ich mich noch beim BIMSB (Berlin Institute for Medical Systems Biology) bedanken, weil ich dort den 3D-Drucker benutzen durfte.

Ich habe KI in Form von ChatGPT benutzt um meinen selbst-geschriebenen Text auf Rechtschreib- und Grammatikfehler zu prüfen. Die KI hat auch einige Unklarheiten gefunden, die ich überarbeiten konnte. Ich habe alles auf Richtigkeit geprüft.

# 9 Anhang

## 9.1 Teileliste

Nr. | Bauteil | Beschreibung | Kosten (€, ca.)
1 | Arduino Uno G3 | Microcontroller | 14,00
2 | LCD 1602 | LCD Display mit 16 Zeichen in 2 Reihen | 6,00
3 | Steckplatine | In einem Elektronik-Lern-Set vorhanden | 4,00
4 | Jumper Kabel | In einem Elektronik-Lern-Set vorhanden | 1,50
5 | Thermistor | TRU Components MJSTS-103-3950-1-600-3D Temperatursensor, bestellt bei Conrad Elektronik | 2,49
6 | FlowSensor | Messing Gehäuse mit Hall Effekt Sensor Bestellt bei Conrad Amazon | 12,93
7 | Widerstände | In einem Elektronik-Lern-Set vorhanden | 2,00
8 | Knöpfe | In einem Elektronik-Lern-Set vorhanden | 2,00
9 | Lötausrüstung | z.B. Lötzinn, Flux, Lötstation, Schrumpfschlauch, Heisluftpistole, Silberdraht, 3. Hand, usw. (Grundausrüstung - hatten wir zu Hause) | 0,00
10 | Potentiometer | 10kΩ lineares Potentiometer | 2,00
11 | Lochrasterplatine | 70mm x 90mm, Rastermaß 2,54mm, Teil eines Sets, bestellt bei Reichelt Elektronik | 2,60
12 | Taster | TRU Components GQ 19H-S bestellt bei Conrad Elektronik | 6,99
13 | Kippschalter | TRU Components TC-MK245 bestellt bei Conrad Elektronik | 1,99
14 | Harz für 3D-Drucker | Wurde mir gestellt, kosten ungefähr 21,50 + 5,20 | 26,70
15 | RJ45 Keystone | Delock 8703, Buchse zum Anschließen der Sensoren, im Gehäuse mit der Platine verdrahtet, bestellt bei Reichelt | 3,95
16 | LAN Internet Kabel | Hatten wir zuhause; eine Seite abgeschnitten und mit den Sensorkabeln verlötet und verschrumpft. | 0,00
17 | Software | Ich habe nur (für Schüler) kostenlose Software benutzt. | 0,00
| | Summe (ca.): | € 89,15

## 9.2 Messwerte zur CPL-Wert Bestimmung

Nr. | Volumen (L) | Wasserhahn | Füllzeit (sec) | HES Counts | CPL
1 | 5 | ganz offen | 25 | 5716 | 1143,20
2 | 5 | ganz offen | 25 | 5726 | 1145,20
3 | 5 | ganz offen | 24 | 5636 | 1127,20
4 | 5 | ganz offen | 24 | 5519 | 1103,80
5 | 5 | ganz offen | 29 | 5605 | 1121,00
6 | 5 | ganz offen | 23 | 5464 | 1092,80
7 | 5 | ganz offen | 24 | 5540 | 1108,00
8 | 5 | ganz offen | 24 | 5513 | 1102,60
9 | 5 | ganz offen | 25 | 5779 | 1155,80
10 | 5 | tlw. offen | 45 | 5673 | 1134,60
11 | 5 | tlw. offen | 36 | 5544 | 1108,80
12 | 5 | tlw. offen | 43 | 5610 | 1122,00
13 | 5 | tlw. offen | 45 | 5653 | 1130,60
14 | 5 | tlw. offen | 47 | 5553 | 1110,60
15 | 5 | tlw. offen | 47 | 5526 | 1105,20
16 | 5 | tlw. offen | 64 | 5487 | 1097,40
17 | 5 | tlw. offen | 42 | 5640 | 1128,00
18 | 5 | tlw. offen | 44 | 5839 | 1167,80
19 | 5 | tlw. offen | 50 | 5635 | 1127,00
20 | 5 | tlw. offen | 56 | 5477 | 1095,40
21 | 8 | ganz offen | 40 | 9366 | 1170,75
22 | 8 | ganz offen | 39 | 9234 | 1154,25
23 | 8 | ganz offen | 40 | 9263 | 1157,88
24 | 8 | ganz offen | 42 | 9540 | 1192,50
25 | 8 | ganz offen | 43 | 9664 | 1208,00
26 | 8 | ganz offen | 55 | 9631 | 1203,88
27 | 8 | ganz offen | 61 | 9527 | 1190,88
28 | 8 | tlw. offen | 79 | 9340 | 1167,50
29 | 8 | tlw. offen | 73 | 9163 | 1145,38
30 | 8 | tlw. offen | 88 | 8882 | 1110,25
31 | 8 | tlw. offen | 89 | 8859 | 1107,38
32 | 8 | tlw. offen | 104 | 8922 | 1115,25
33 | 8 | tlw. offen | 60 | 9480 | 1185,00
34 | 8 | tlw. offen | 102 | 8985 | 1123,13
35 | 8 | tlw. offen | 79 | 8990 | 1123,75
36 | 10 | ganz offen | 52 | 11988 | 1198,80
37 | 10 | ganz offen | 48 | 11169 | 1116,90
38 | 10 | ganz offen | 52 | 11824 | 1182,40
39 | 10 | ganz offen | 51 | 11670 | 1167,00
40 | 10 | ganz offen | 51 | 11781 | 1178,10
41 | 10 | ganz offen | 50 | 11697 | 1169,70
42 | 10 | ganz offen | 47 | 11207 | 1120,70
43 | 10 | ganz offen | 48 | 11871 | 1187,10
44 | 10 | tlw. offen | 94 | 10958 | 1095,80
45 | 10 | tlw. offen | 72 | 11440 | 1144,00
46 | 10 | tlw. offen | 105 | 11091 | 1109,10
47 | 10 | tlw. offen | 84 | 11258 | 1125,80
48 | 10 | tlw. offen | 99 | 11342 | 1134,20
49 | 10 | tlw. offen | 101 | 11490 | 1149,00
50 | 10 | tlw. offen | 98 | 11639 | 1163,90
51 | 10 | tlw. offen | 102 | 11785 | 1178,50

[^1] Elegoo.com (2025): ELEGOO UNO R3 Project The Most Complete Starter Kit Tutorial, [online] https://eu.elegoo.com/blogs/arduino-projects/elegoo-uno-r3-project-the-most-complete-starter-kit-tutorial [abgerufen am 12.01.2025].
[^2] Wikipedia.org (2025): Steinhart-Hart Gleichung, [online] https://de.wikipedia.org/wiki/Steinhart-Hart-Gleichung [abgerufen am 12.01.2025].
[^3] Wikipedia.org (2025): Hall-Effekt, [online] https://de.wikipedia.org/wiki/Hall-Effekt [abgerufen am 12.01.2025].
[^4] Arduino.cc (2025): Software | Arduino, [online] https://www.arduino.cc/en/software [abgerufen am 12.01.2025].
[^5] Arduino.cc (2025): Arduino Reference, [online] https://www.arduino.cc/reference/cs/ [abgerufen am 12.01.2025].
[^6] Amazon.de (2025): 1-30L / min Wasserdurchflussschalter, [online] https://www.amazon.de/gp/product/B07XDZ25SY/ref=ppx_yo_dt_b_search_asin_image?ie=UTF8&psc=1 [abgerufen am 12.01.2025].
[^7] Conrad.de (2025): TRU COMPONENTS MJSTS-103-3950-1-600-3D, [online] https://www.conrad.de/de/p/tru-components-mjsts-103-3950-1-600-3d-temperatursensor-30-bis-105-c-10-k-3950-k-1570951.html [abgerufen am 12.01.2025].
[^8] Arduino.cc (2025): Arduino Starter Kit Multi-language, [online] https://store.arduino.cc/products/arduino-starter-kit-multi-language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 [abgerufen am 12.01.2025].
[^9] Elegoo.com (2025): ELEGOO 37 in 1 Sensor Modules Kit Tutorial, [online] https://www.elegoo.com/blogs/arduino-projects/elegoo-37-in-1-sensor-modules-kit-tutorial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 [abgerufen am 12.01.2025].
[^10] Autodesk.com (2025): Autodesk Eagle, [online] https://www.autodesk.com/products/eagle/ [abgerufen am 12.01.2025].
[^11] Autodesk.com (2025): Autodesk Fusion, [online] https://www.autodesk.com/products/fusion-360 [abgerufen am 12.01.2025].
[^12] Keyence.de (2025): AGILISTA-3200W, [online] https://www.keyence.de/products/3d-printers/3d-printers/agilista-3100/models/agilista-3200w/ [abgerufen am 12.01.2025].
[^13] Arduino.cc (2025): Liquid Crystal Displays (LCD) with Arduino, [online] https://docs.arduino.cc/learn/electronics/lcd-displays/ [abgerufen am 13.01.2025].
[^14] Github (2025): rzinzen / S4F, [online] https://github.com/rzinzen/S4F [abgerufen am 12.01.2025].
[^15] Fluke (2025): What is Ohm’s Law? (Electrical, Fundamentals), [online] https://www.fluke.com/en/learn/blog/electrical/what-is-ohms-law [abgerufen am 13.01.2025].
[^16] SRS (2025): Thermistor Calculator v1.1, [online] https://www.thinksrs.com/downloads/programs/therm%20calc/ntccalibrator/ntccalculator.html [abgerufen am 12.01.2025].
[^17] Kurz vor Abgabe der Arbeit habe ich Verbesserungen am Code vorgenommen. Die derzeitige Version ist 3.1 und auf GitHub verfügbar14. Änderungen sin in den „Version Notes“ des Codes dokumentiert.
[^18] Arduino.cc (2025): attachInterrupt(), [online] https://www.arduino.cc/reference/cs/language/functions/external-interrupts/attachinterrupt/ [abgerufen am 12.01.2025].
[^19] Stadtwerke Bernau (2025): Stadtwerke Neukunden – NK-Portal, [online] https://kundenportal.stadtwerke-bernau.de/Neukunden/Neukunden/Tarifuebersicht [abgerufen am 12.01.2025].
[^20] Wikipedia.org (2025): Keystone Module, [online] https://en.wikipedia.org/wiki/Keystone_module [abgerufen am 14.01.2025].
[^21] Den Durchflusssensor als Turbine zu verwenden wäre eine sehr komplexe Herausforderung, da dies den Einsatz des Propellers zum Antrieb eines Motors erfordert. Wenn der Motor eine Batterie lädt, entsteht ein erhöhter (wahrscheinlich variabler) Widerstand und der CPL-Wert wäre evtl. variabel.

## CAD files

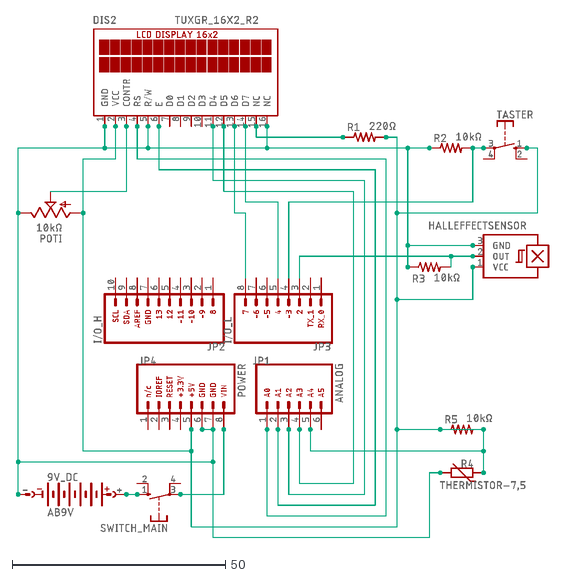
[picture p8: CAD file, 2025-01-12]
WireingDiagram-S4F_Shield.dxf
125.1 x 122.5

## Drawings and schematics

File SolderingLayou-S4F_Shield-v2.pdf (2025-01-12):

# ABCDEFGHIJKLMNOPQRSTUVWXYZABCDE

# Arduino

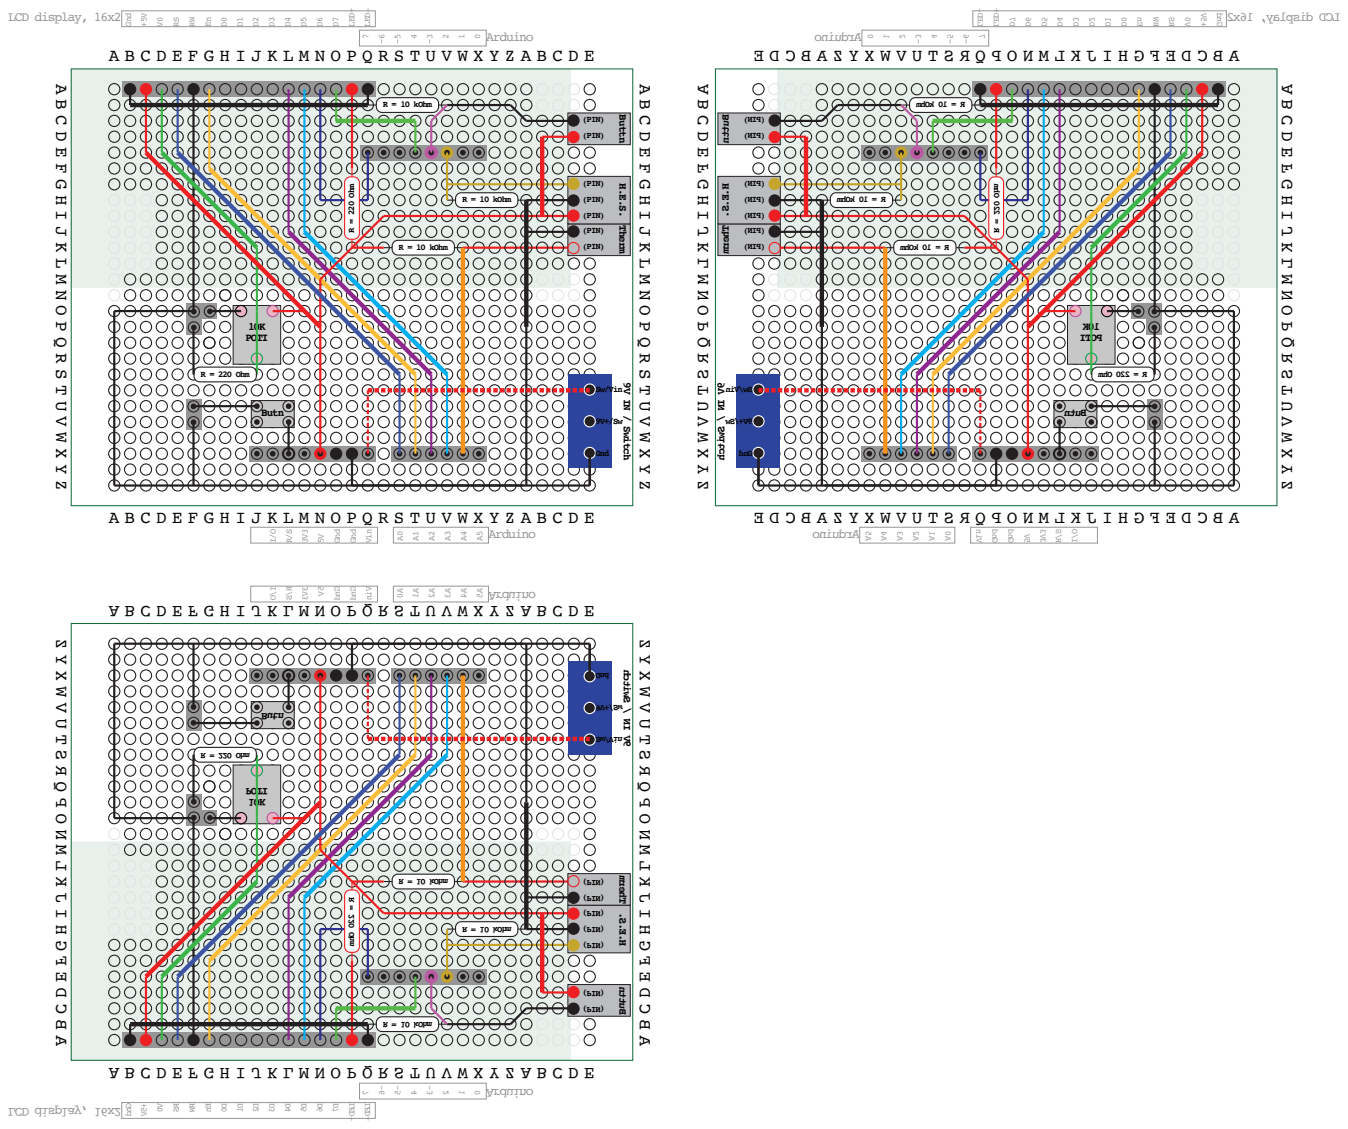
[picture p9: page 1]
LCD display, 16x2; I/O R/S 3V3 5VGnd Gnd Vin; Arduino; ABCDEFGHIJKLMNOPQRSTUVWXYZ; R = 10 kOhm; 10K POTI; Butn; Sw/Vin; Gnd; (PIN) (PIN); (PIN) (PIN) (PIN); R = 220 Ohm; ABCDEFGHIJKLMNOPQRSTUVWXYZABCDE; ABCDEFGHIJKLMNOPQRSTUVWXYZABCDE Gnd +5V V0RSRWEnD0D1D2D3D4D5D6D7LED+ LED- LCD display, 16x2; A0A1A2A3A4A5Arduino 7~6~5 4~3 2 1 0Arduino ABCDEFGHIJKLMNOPQRSTUVWXYZ; POTI; (PIN); Vin; ABCDEFGHIJKLMNOPQRSTUVWXYZ R = 10 kOhm

ABCDEFGHIJKLMNOPQRSTUVWXYZABCDE Gnd +5V V0RSRWEnD0D1D2D3D4D5D6D7LED+ LED-

9V IN / Switch Buttn Therm H.E.S.

9V IN / Switch Buttn Therm H.E.S. R = 10 kOhm

Gnd

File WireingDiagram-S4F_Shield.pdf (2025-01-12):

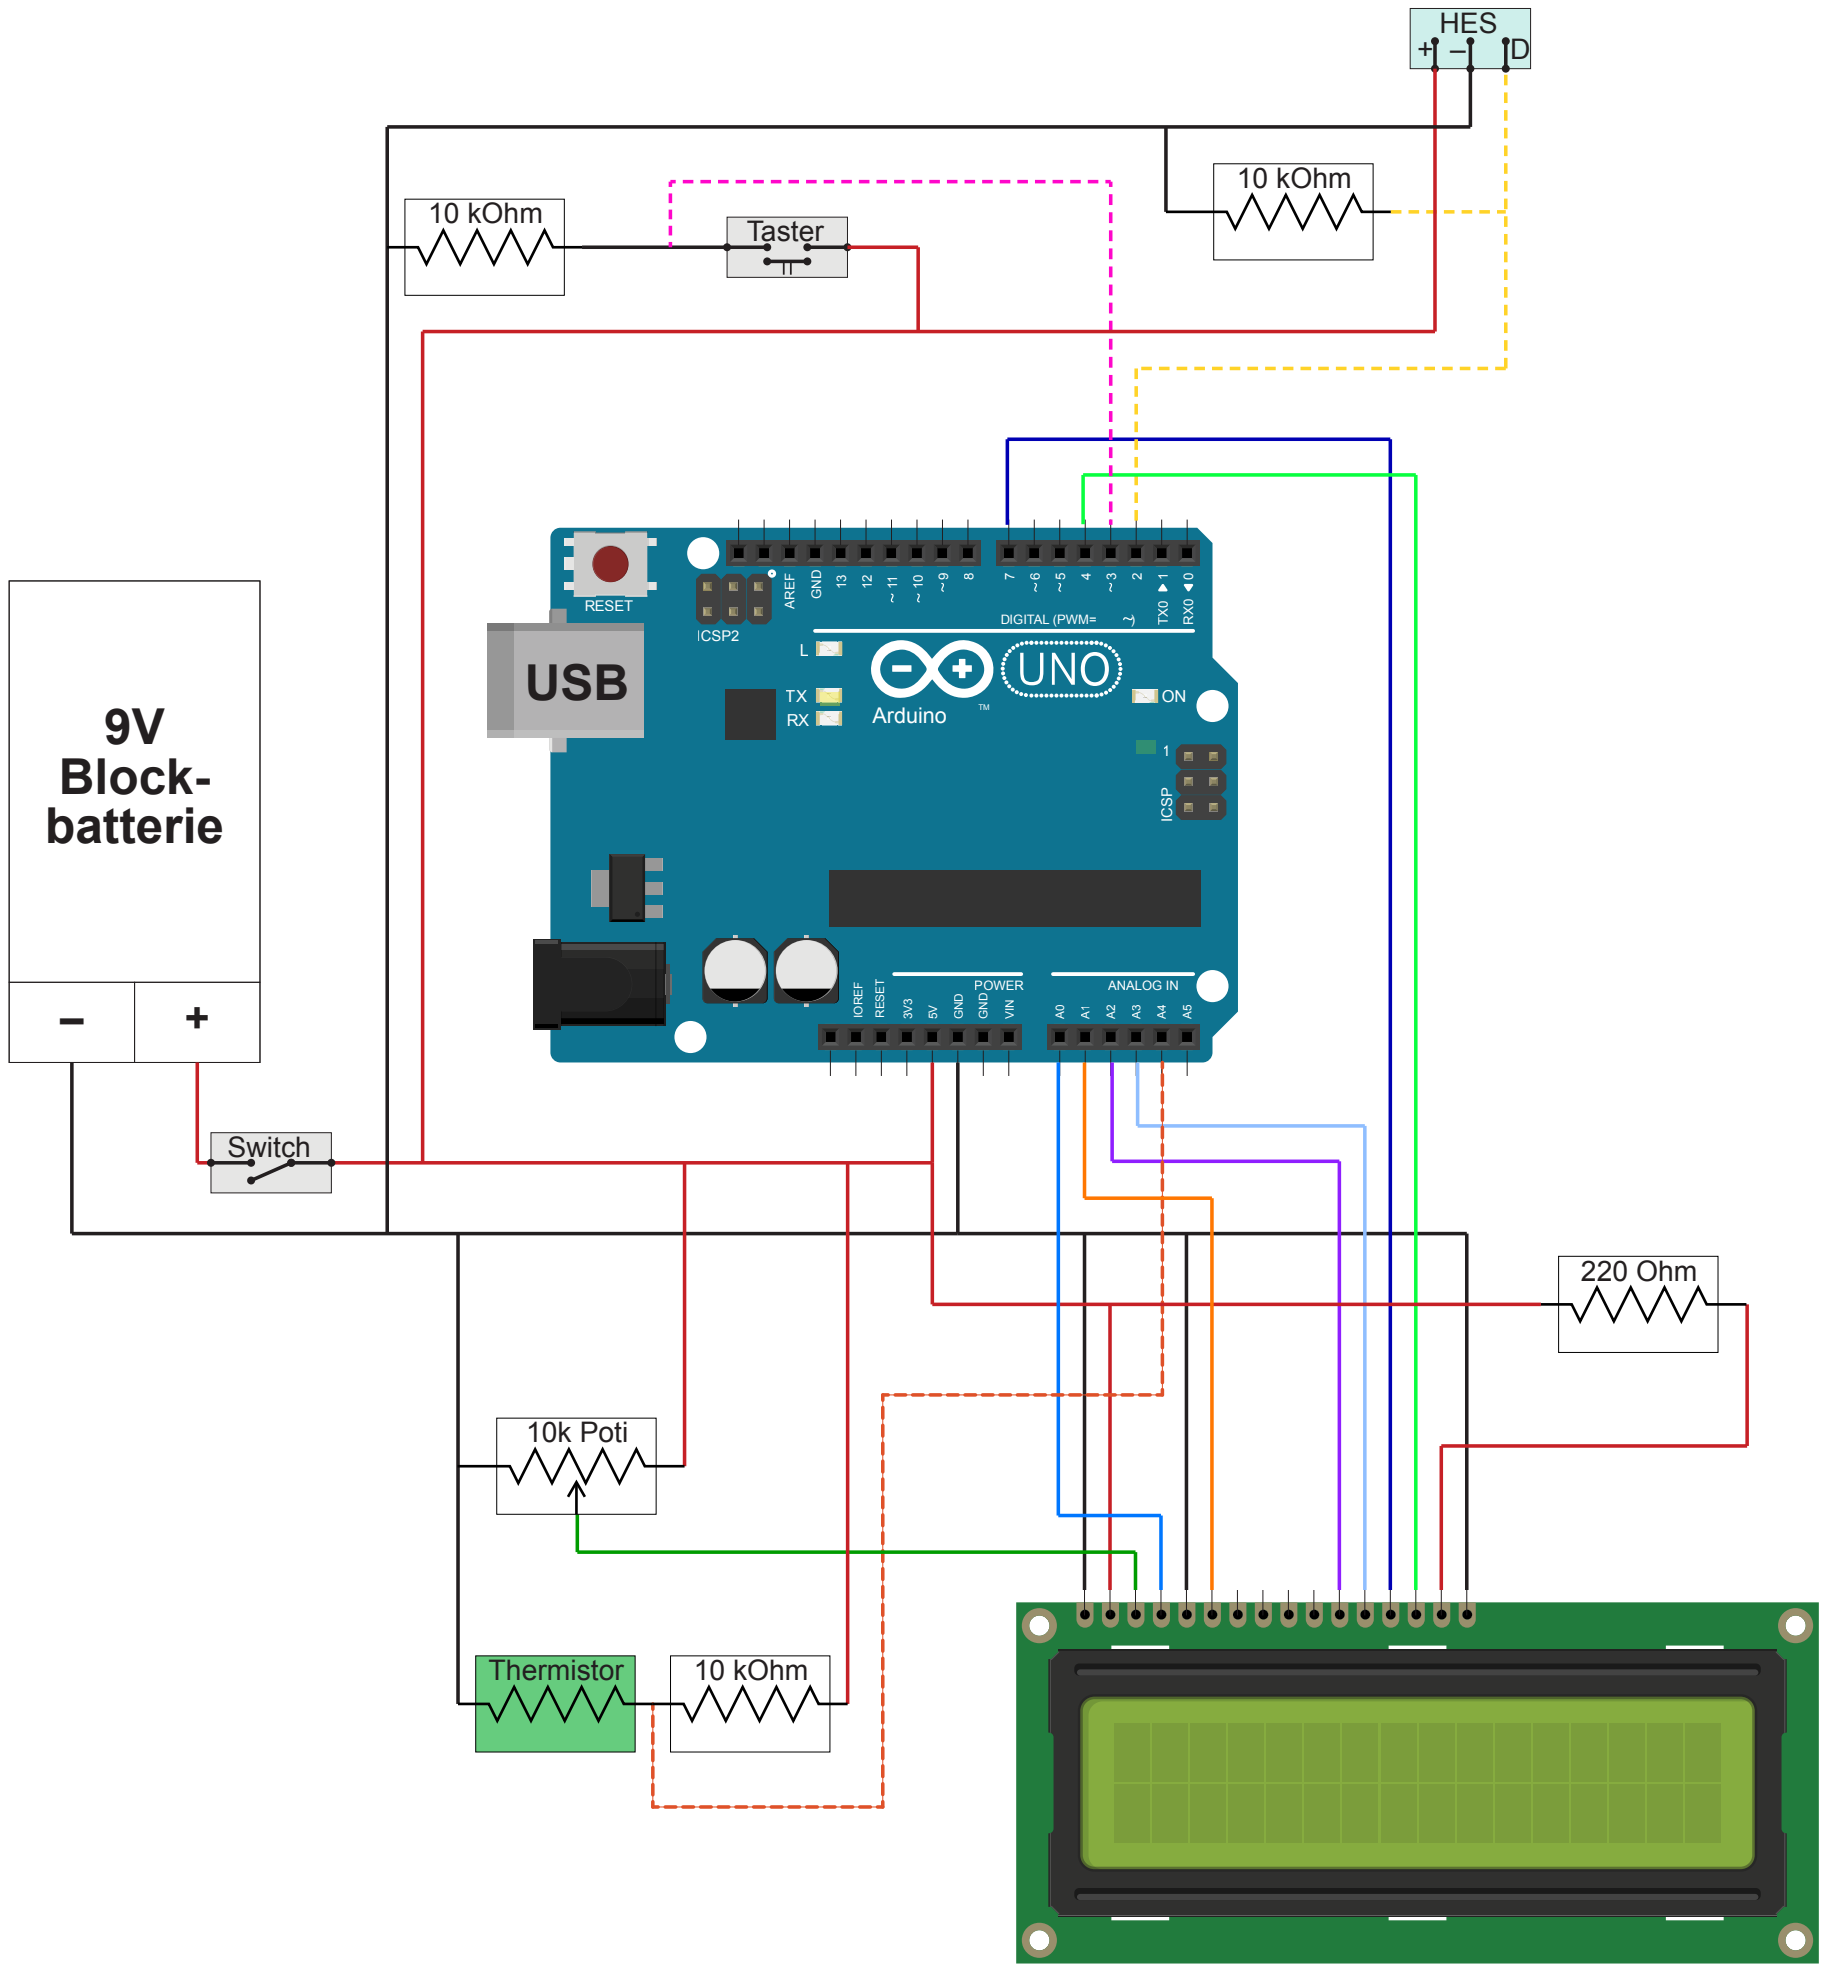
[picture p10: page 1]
ANALOG IN; AREF; GND; RESET; VIN; DIGITAL (PWM=; Arduino TM; IOREF; ICSP; ICSP2; POWER; 9V Block- batterie; Switch; Taster; HES; 10k Poti; 220 Ohm; Thermistor; 10 kOhm; USB

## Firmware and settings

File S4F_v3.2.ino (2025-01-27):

/*
Version Notes:
Version 3.0
  MAJOR:
    - calling MeasureTemp() now depends on a minimum hall count (HallThreshold). ==> TempSum and TempAvg now better reflect water actually used, rather than being subject to temp change while idle
    - MeasureFlow() now contains an offset counter to better reflect actual shower time --> when Hall count < HallThreshold, then TimeNoflow is increased by the measuring interval.
  MINOR:
    - the CheckSensor block now resides in setup(), where it belongs.
    - better re-zeroing opf variables in setup()
Version 3.1
  MINOR:
    - introduced if-loop to make sure temp measurements are not skewed due to bad contactVersion 3.1
Version 3.2
  MINOR:
    - introduced timer in display and re-aranged display info
*/

#include <LiquidCrystal.h>              //includes library to use LCD display

//Software Version
String Version = "S4F_v3.1  ";
String Author = "Oliver Zinzen";

//Pin definitions
  const int ThermistorPin = 4;    //defines the thermistor pin (voltage devider) as a constant and an integer (Pin number)
  const int HallPin = 2;          //defines the thermistor pin (voltage devider) as a constant and an integer (Pin number)
  const int ButtonPin = 3;        //defines the button pin as a constant and an integer (Pin number)
  LiquidCrystal lcd(14, 15, 16, 17, 7, 4);  //defines LCD display communicationn pins

//Variables for input
  int ButtonState = 0;          //defines the initial ButtonState variable as 0

//Time values  (Note: if stored as unsigned 4-byte long values, overflow limit is ~50 days)
  unsigned int Std = 1000;            //sets a standard variable for time delays 
  unsigned long TimeStart = 0;        //sets a variable to store a time value (here: StartTime) as a long (4bytes) unsigned integer
  unsigned long TimeStop = 0;         //sets a variable to store a time value (here: Stop time) as a long (4bytes) unsigned integer
  unsigned long TimeNow = 0;          //sets a variable to store a time value (here: Current time) as a long (4bytes) unsigned integer
  unsigned long TimeNoflow = 0;       //sets a variable to store a time value (here: Time with no  water flow) as a long (4bytes) unsigned integer
  unsigned long Duration = 0;         //sets a variable to store a time value (here: Duration) as a long (4bytes) unsigned integer
  unsigned long DurationFlow = 0;     //sets a variable to store a time value (here: DurationFlow) as a long (4bytes) unsigned integer
  unsigned long LastMeasureInfo = 0;  //sets a variable to store the last measurement time
  unsigned long LastMeasureFlow = 0;  //sets a variable to store the last measurement time
  unsigned long LastMeasureTemp = 0;  //sets a variable to store the last measurement time
  unsigned int Interval = 1000;       //sets measurement interval
  unsigned int IntervalInfo;          //sets measurement interval
  unsigned int IntervalFlow;          //sets measurement interval
  unsigned int IntervalTemp;          //sets measurement interval
  unsigned long ExitTimer;            //sets variable to unsigned long value
 
//Thermistor variables
  int ADCout;           //defines ADCout value as an integer (this is 10-bit, 0-1023)
  float Vref = 5.0;     //defines the reference voltage (Vref, aka Vin) for the ADC, in Arduino Uno this is 5V (defined as float, b/c calculations involving it need to result in floats)
  float Vout;           //defines the voltage devider voltage as a decimal
  float R1 = 10000.0;   //defines the value of the static Resistor in the voltage devider (in Ohm) as a decimal
  float R2;             //defines the variable R2 (for Thermistor reistance) as a decimal
  float lnR2;           //defines the variable lnR2 (natural log of R2) as a decimal
  const float A = 1.105646556e-3;   //defines the thermistor variable c1 in the Steinhart-Hart equation as a float of constant value
  const float B = 2.369707092e-4;   //defines the thermistor variable c2 in the Steinhart-Hart equation as a float of constant value
  const float C = 8.420273017e-8;   //defines the thermistor variable c3 in the Steinhart-Hart equation as a float of constant value
  float Temp_C = 0.0;               //defines the variable as a decimal
  float Temp_K, TempAvg;            //defines the variables for as a decimal
  float TempSum = 0.0;              //defines the varable T_C_sum to keep a running sum of measured temperatures, 
  unsigned int N_Temp = 0;          //defines the varable to count measurement iterations

//Hall Effect Sensor variables
  unsigned int HallCount = 0;       //defines the variable for Hall Effect Sensor Counts as an unsigned integer
  float CPM = 0.0;                  //defines Counts per Minute as an unsigned integer
  const float CPL = 1141.25;        //defines the constant to convert counts to liters
  float FlowRate = 0.0;             //defines the FlowRate variable (in L/min) as a float 
  float FlowRateAvg;                //defines the average FlowRate as a float
  float FlowRateSum = 0.0;          //defines the varable as a float to keep a running sum of measured Flow Rates
  unsigned int N_FlowRate = 0;      //defines the varable to count measurement iterations
  float Volume = 0.0;               //defines the variable for water consumption (in L)

//other variables
  int MinSinceStart = 0;
  int SecSinceStart = 0;
  bool SensorCheck = false;
  int TempErrorCount = 0;                   //sets a variable to count potential faulty temp measurements, as a loose sensor connection would result in a calculated temp of absolute Zero
  unsigned int HallThreshold = 50;          //sets the threshold for Hall impulses accumulated in interval to be considered flow
  const float TempBase = 18.0;              //temperature of unheated water as base for energy calculation (in °C)
  const float c_Water_kWh = 1.1622e-3;      //specific heat os water in [kWh/(kg*°C)] -- it is 4184 J/(kg*C) and 3.6E6 J/kWh
  float Energy = 0;                         //Variable defined as float
  const float EnergyPrice = 0.28;           //price per kWh in Bernau-Barnim assuming yearlu usage of 5000kWh is approx.
                                              //0.13 Euro / kWh for Gas (Stadtwerke Bernau)
                                              //0.37 Euro / kWh for Electricity (Stadtwerke Bernau)
                                              //0.18 Euro / kWh for Gas (E.On = Grundversorger)
                                              //0.41 Euro / kWh for Electricity (E.On = Grundversorger)
                                              //--> use 0.28 Euro/kWh as a reasonable approximation for cost
  const float WaterPrice = 0.00586;         //price for water in Panketal is 2.78 Euro/m^3 + 3.08 Euro/m^3 drain water = 5.86 Euro/m^3
                                              //1m^3 = 1000L --> 0.00586 Euro/L
  float Cost; 

//==================================================
//==================================================
//==================================================

void setup() {

  Serial.begin(115200);             //begin serial communication at 115200 bits/sec
  pinMode(ButtonPin, INPUT);        //sets the ButtonPin to input mode
  pinMode(HallPin, INPUT_PULLUP);   //sets the ButtonPin to input mode
  attachInterrupt(digitalPinToInterrupt(HallPin), CountHallPulses, CHANGE); //designates the HallPin (2) to call the count() function if status change is detected
  
  lcd.begin(16, 2);                 //initializes LCD as a 16-column, 2-row display

  //The following lines display Welcome & Info message 
    lcd.clear();
    lcd.print("Showers 4 Future");
    lcd.setCursor(0, 1);
    lcd.print(" Jugend Forscht ");
    delay(Std);
    lcd.setCursor(0, 1);
    lcd.print("by ");
    lcd.print(Author);
    delay(Std);
    lcd.setCursor(0, 1);
    lcd.print("Ver.:  ");
    lcd.print(Version);
    delay(Std);

  //check if sensors are connected
  SensorCheck = true;
  MeasureTemp();
  if (Temp_C < -20) {
    Serial.println("SENSOR WARNING !!!");
    lcd.clear();
    lcd.print("Sensor not found");
    lcd.setCursor(0, 1);
    lcd.print("check connection");
    while (Temp_C <= -20) {
      delay(2000);
      if (digitalRead(ButtonPin) == HIGH) {
        
        Serial.println("Sensor Check has been skipped.");
        lcd.clear();
        lcd.print("Skipping");
        lcd.setCursor(0, 1);
        lcd.print("Sensor Check");
        delay(2000);
        break;
      }
      MeasureTemp();
    }
  }

  //re-set basic variables
    ButtonState = 0;
    TimeStart = 0;
    TimeStop = 0;
    TimeNoflow = 0;
    Temp_C = 0.0;
    TempSum = 0.0;
    TempAvg = 0.0;
    N_Temp = 0;
    SensorCheck = false;
    TempErrorCount = 0; 
    HallCount = 0; 
    FlowRate = 0.0;
    FlowRateSum = 0.0;
    N_FlowRate = 0;
    Volume = 0;
    Energy = 0;

  //Wait for start command
    lcd.clear();
    lcd.print("Press button to");
    lcd.setCursor(0, 1);
    lcd.print("measure...");

    Serial.println("\n" "Waiting for Button to be pressed...");
  
    while (digitalRead(ButtonPin) == LOW) {        //empty while loop to wait for button press to exit
      //empty
    }
    lcd.clear();
    lcd.print("OK! ...beginning");
    lcd.setCursor(0, 1);
    lcd.print("(press to stop)");
    delay(Std);
    lcd.clear();                  //clears the display
  
  //sets the reference time of "Button Push" as time since boot
    TimeStart = millis();         //sets the base time
    Serial.println();
    Serial.print("Ref. Start time since boot: 'TimeStart' = ");
    Serial.println(TimeStart);
}

//==================================================
void loop() {
  TimeNow = millis();
  IntervalInfo = 1 * Interval;    //sets measurement interval for information report (in milliseconds)
  IntervalFlow = 6 * Interval;    //sets measurement interval for FLOW measurement (in milliseconds)
  IntervalTemp = 2 * Interval;    //sets measurement interval for TEMP measurement (in milliseconds)

  //if the condition is met, the program beginns exiting
  if (digitalRead(ButtonPin) == HIGH) {
    TimeStop = millis();                  //records stoppage time
    Duration = TimeStop - TimeStart;      //calculates duration in milliseconds
    if (TimeNoflow > Duration) {
      TimeNoflow = Duration;
    }
    DurationFlow = Duration - TimeNoflow; //adjusts the Duration variable for time with flow
   
    Volume = (float(Duration)/(1000.0*60.0)) * FlowRateAvg;     //calculates consumed water volume (in L)
    Energy = Volume * c_Water_kWh * (TempAvg - TempBase);       //calculates energy (in kWh) needed to consumed heat water
    Energy = Energy / 0.7;                                      //Adjusts Energy use assuming a Water heater efficiency of 70%
    Cost = (Energy * EnergyPrice) + (Volume * WaterPrice);      //calculates approx price based on Energy + Water


    //Seial.print stoppage info
      Serial.print("'TimeStop' = ");
      Serial.println(TimeStop); 
      Serial.println();

      Serial.print("Duration since measuement start (sec)\t");
      Serial.println(Duration / 1000);
      Serial.print("Duration with flow (sec)\t");
      Serial.println(DurationFlow / 1000);
    //Seial.print results info
      Serial.print("Volume (L)\t");
      Serial.println(Volume);

      Serial.print("AvgTemp (°C)\t");
      Serial.println(TempAvg);
      
      Serial.print("Energy (Wh)\t");
      Serial.println(Energy*1000);
      
      Serial.print("Cost (Euro)\t");
      Serial.println(Cost);
    //LCD - Stoppage info
      lcd.clear();
      lcd.print("Program has been.");
      lcd.setCursor(0, 1);
      lcd.print("stopped !");
      delay(Std);

    //LCD - Results will follow and loop
      lcd.clear();
      lcd.print("Results Summary:");
      lcd.setCursor(0, 1);
      lcd.print("(info will loop)");
      delay(Std);

    //The following is the results info loop
    while (ButtonState == 0 ) {
      //LCD - Duration Info
        lcd.clear();
        lcd.print("Shower time:");
        lcd.setCursor(1, 1);
        lcd.print(float(DurationFlow)/(1000.0*60.0));
        lcd.print(" min");
        delay(Std*3);
      //LCD - Volume Info
        lcd.clear();
        lcd.print("Water Volume:");
        lcd.setCursor(1, 1);
        lcd.print(Volume);
        lcd.print(" L");
        delay(Std*3);
      //LCD - Temp Info
        lcd.clear();
        lcd.print("Average Temp.:");
        lcd.setCursor(1, 1);
        lcd.print(TempAvg);
        lcd.print(" ");
        lcd.print((char)223);
        lcd.print("C");
        delay(Std*3);
      //LCD - Energy Info
        lcd.clear();
        lcd.print("Approx. Energy:");
        lcd.setCursor(1, 1);
        lcd.print(Energy*1000);
        lcd.print(" Wh");
        delay(Std*3);
      //LCD - Cost Info
        lcd.clear();
        lcd.print("Approx. Cost:");
        lcd.setCursor(1, 1);
        lcd.print(Cost);
        lcd.print(" Euro");
        delay(Std*3);
      //LCD - Exit Option
        lcd.clear();
        lcd.print("Press Button now");
        lcd.setCursor(1, 1);
        lcd.print("to exit Loop.");
      //Exit timer
        ExitTimer = millis();
        while (millis()-ExitTimer <= 3*Std) {
          if (digitalRead(ButtonPin) == HIGH) {
            ButtonState = 1;
          }
        }
    }
    ButtonState = 0;          //resets ButtonState after exiting while loop
    lcd.clear();
    lcd.print("Restarting...");
    lcd.setCursor(0, 1);
    lcd.print("turn off anytime");
    delay(Std*2);
    setup();                  //exits while-loop when button press causes ButtoPin pull-up to HIGH
  }
  
  //to take measurements at defined intervals:
  
  if (TimeNow - LastMeasureFlow >= IntervalFlow) {
    MeasureFlow();
  }

  if (HallCount > HallThreshold) {                      //to measure Temp and update TempAvg, this requires that there is flow (to avoid average temp decreasing artificially) 
    if (TimeNow - LastMeasureTemp >= IntervalTemp) {
      MeasureTemp();
      }
  }

  if (TimeNow - LastMeasureInfo >= IntervalInfo) {
    ReportInfo();
  }
 
}

//==================================================
void CountHallPulses() {
  HallCount++;
}

//==================================================
void ReportInfo() {
  
  //Report to Serial Monitor
  Serial.print(N_FlowRate);
  Serial.print("\tFlow =\t");
  Serial.print(FlowRate);
  Serial.print("\tL/min\t\t(-> Avg Flow\t");
  Serial.print(FlowRateAvg);
  Serial.println("\tL/min)");

  Serial.print(N_Temp);
  Serial.print("\tTemp = \t");
  Serial.print(Temp_C);
  Serial.print("\t°C\t\t(-> Avg Temp\t");
  Serial.print(TempAvg);
  Serial.println("\t°C)\n");   

////Report to LCD

  //Temp report
    lcd.clear();
    lcd.print(Temp_C);
    lcd.setCursor(5, 0);
    lcd.print((char)223);
    lcd.print("C");

  //Time Report
    MinSinceStart = int(((TimeNow - TimeStart)/1000)/60);
    SecSinceStart = int(((TimeNow - TimeStart)/1000) - (MinSinceStart * 60));
    if (MinSinceStart<10) {
      lcd.setCursor(12,0);
    } else {
      lcd.setCursor(11,0);
    }
    lcd.print(MinSinceStart);
    lcd.print(":");
    if (SecSinceStart<10) {
      lcd.print("0");
    }
    lcd.print(SecSinceStart);

    //Flow Report
    lcd.setCursor(0, 1);
    lcd.print(FlowRate);
    lcd.setCursor(5, 1);
    lcd.print("L/min");

  LastMeasureInfo = millis();

}

//==================================================
void MeasureFlow() {
  CPM = ((HallCount) / (IntervalFlow/1000)) * 60;   //converts counts to counts per minute
  FlowRate = CPM / CPL;                             //calculates current FlowRate in L/min
  N_FlowRate++;
  if (HallCount < HallThreshold) {                  //runs only if waterflow is close to nothing for the vast majority of the interval
    TimeNoflow = TimeNoflow + IntervalFlow;         //this increases an Shower time offset: time without flow should not be counted as shower time
  }
  FlowRateSum = FlowRateSum + FlowRate;             //keeps a running sum of flow rate measurements
  FlowRateAvg = FlowRateSum / N_FlowRate;           //updates the average FlowRate measured since start
  HallCount = 0;                                    //Resets the HallCount variable

  LastMeasureFlow = millis();
}

//==================================================
void MeasureTemp() {
  ADCout = analogRead(ThermistorPin);     //ADCout variabler defined as ADC value read at the thermistor (Arduino ADCs are 10 bit; 2^10 = 1024)
  Vout = (float)ADCout / 1023.0 * Vref;   //calculates the Vout voltage and defines it as the variable Vout
  R2 = R1 / ((Vref / Vout) - 1.0);        //R2 calculated via the voltage devider equation solved for R2
  lnR2 = log(R2);                         //defines the variable lnR2 as the natural log (base e) transformed value of the variable R2
  Temp_K = (1.0 / (A + B * lnR2 + C * lnR2 * lnR2 * lnR2));  //Steinhart-Hart equation. Calculates the temperature (in K) based on the log-transformed calculated R2 and the thermistor constants A, B & C
 
  if ((Temp_K - 273.15 <= -20) && (SensorCheck == false)) {
    Temp_C = Temp_C;
    TempErrorCount++;
    if (TempErrorCount >= 5) {
      lcd.clear();
      lcd.print("Check Sensor Con.");
      lcd.setCursor(0, 1);
      lcd.print("Push to Restart!");
      if (digitalRead(ButtonPin) == HIGH) {
        setup();
      }
    }
  } else {
    Temp_C = Temp_K - 273.15;               //converts Kelvin (T_K) to °C (T_C)
  }
    N_Temp++;                               //keeps a running tally of measurement iterations, incrementing by +1
    TempSum = TempSum + Temp_C;             //keeps a running sum of temperature measurements
    TempAvg = TempSum / N_Temp;             //updates the average temperature measured since start 
    LastMeasureTemp = millis();
  }

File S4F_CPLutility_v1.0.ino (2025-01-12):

/*
The point of this sketch is to determine the Counts per Liter (CPL) value.
The impulse counts given by the Hall Effect Sensor should relate proportionally to the Volume of water passing through it.
*/

#include <LiquidCrystal.h>              //includes library to use LCD display

//Global variables:

const int HallPin = 2;          //defines the thermistor pin (voltage devider) as a constant and an integer (Pin number)
const int ButtonPin = 3;        //defines the button pin as a constant and an integer (Pin number)
LiquidCrystal lcd(14, 15, 16, 17, 7, 4);  //defines LCD display communicationn pins

unsigned int Std = 500;         //sets std time value to 0.5sec
unsigned int Iteration = 0;   
unsigned int HallCount;         
unsigned long TimeStart;
unsigned long TimeStop;

void setup() {
  Serial.begin(115200);             //begin serial communication at 9600 bits/sec
  Serial.print("Serial Comms established!");

  lcd.begin(16, 2);                 //initializes LCD as a 16-column, 2-row display
  lcd.print("LCD Comms ready");
  lcd.setCursor(0, 1);
  lcd.print("CPL utility prog");
  
  pinMode(ButtonPin, INPUT);        //sets the ButtonPin to input mode
  pinMode(HallPin, INPUT_PULLUP);   //sets the ButtonPin to input mode
  attachInterrupt(digitalPinToInterrupt(HallPin), CountHallPulses, CHANGE); //designates the HallPin (2) to call the count() function if status change is detected

  delay(Std*4);
}

void loop() {
    
  lcd.clear();
  lcd.print("push button to ");
  lcd.setCursor(0, 1);
  lcd.print("start counting..");

  while (digitalRead(ButtonPin) == LOW) {
 
  }
  delay(200);             //short delay to prevent button bounce from registering

  HallCount = 0;
  TimeStart = millis();
  
  lcd.clear();
  lcd.print("counting.....");    
  
  while (digitalRead(ButtonPin) == LOW) {
    //empty loop to wait for button push
  }
  delay(200);             //short delay to prevent button bounce from registering

  TimeStop = millis();
  Iteration++;

  Serial.print("\n No. ");
  Serial.println(Iteration);
  Serial.print("Time (sec):\t");
  Serial.println((TimeStop - TimeStart) / 1000.0); 
  Serial.print("Counts:\t");
  Serial.println(HallCount);

  lcd.clear();
  lcd.print(Iteration);
  lcd.print(" Time:");
  lcd.setCursor(8, 0);
  lcd.print((TimeStop - TimeStart) / 1000);
  lcd.setCursor(0, 1);
  lcd.print("Counts:");
  lcd.setCursor(8, 1);
  lcd.print(HallCount);

  delay(Std*2);

  while (digitalRead(ButtonPin) == LOW) {
    //empty loop to wait for button push
  }
  delay(100);             //short delay to prevent button bounce from registering

}

void CountHallPulses() {
  HallCount++;
}
